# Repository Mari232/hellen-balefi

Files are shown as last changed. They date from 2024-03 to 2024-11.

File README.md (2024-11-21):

# FAQ

Q: How do I get latest hellen-one?

A: ``.github/workflows/update-hellen-one-reference.yaml`` is set to pull latest hellen daily!

Q: I get error 'Cannot stat xx-yy__zz.kicad_pcb: No such file' but files are right there?

A: please do not use dashes and underscore symbols in file names.

Q: Automation says that aux_axis_origin is missing?

A: aux_axis_origin is required, please place it in the appropriate corner.

Q: I get "Cannot parse position" with negative value?

A: Please move origin point into left-bottom corner of the board since we cannot parse negative coordinates at the moment. See https://github.com/andreika-git/hellen-one/issues/349

Q: I am placing an order with JLCPCB and component orientation all looks wrong?!

A: See https://github.com/rusefi/uaefi/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

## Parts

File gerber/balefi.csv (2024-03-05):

Comment | Designator | Footprint | LCSC Part #
MountingHole_Pad | H1 | MountingHole:MountingHole_3.7mm_Pad_Via
MountingHole_Pad | H2 | MountingHole:MountingHole_3.7mm_Pad_Via
MountingHole | H3 | MountingHole:MountingHole_3.7mm
Connectors_EFI_ECUs_Con_825213-1 | J1 | rusefi_lib:825213-1_FIAT
Module-knock-0.2 | M1 | hellen-one-knock-0.2:knock
Module:mega-mcu100/0.3 | M2 | hellen-one-mega-mcu100-0.3:mega-mcu100
Module-vr-discrete-0.4 | M3 | hellen-one-vr-discrete-0.4:vr-discrete
Module-vr-discrete-0.4 | M4 | hellen-one-vr-discrete-0.4:vr-discrete
Q_NIGBT_GCE | Q1 | Package_TO_SOT_SMD:TO-252-2
Q_NIGBT_GCE | Q2 | Package_TO_SOT_SMD:TO-252-2
Q_NMOS_GDS | Q3 | Package_TO_SOT_SMD:TO-252-2
Q_NMOS_GDS | Q4 | Package_TO_SOT_SMD:TO-252-2
Q_NMOS_GDS | Q5 | Package_TO_SOT_SMD:TO-252-2
Q_NMOS_GDS | Q6 | Package_TO_SOT_SMD:TO-252-2
1k | R1 | Resistor_SMD:R_0603_1608Metric
1k | R2 | Resistor_SMD:R_0603_1608Metric
330 | R3 | Resistor_SMD:R_0603_1608Metric
68k | R4 | Resistor_SMD:R_0603_1608Metric
330 | R5 | Resistor_SMD:R_0603_1608Metric
68k | R6 | Resistor_SMD:R_0603_1608Metric
330 | R7 | Resistor_SMD:R_0603_1608Metric
68k | R8 | Resistor_SMD:R_0603_1608Metric
330 | R9 | Resistor_SMD:R_0603_1608Metric
68k | R10 | Resistor_SMD:R_0603_1608Metric

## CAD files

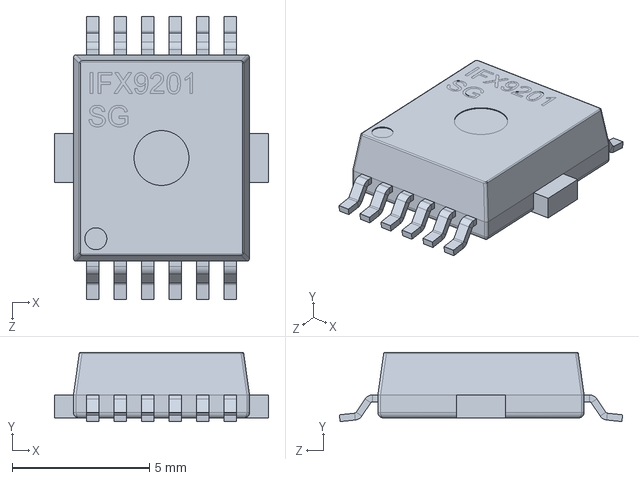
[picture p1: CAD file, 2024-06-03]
balefi-libraries/3d_models/IFX9201SG.STEP
7.80 x 2.52 x 10.3 mm

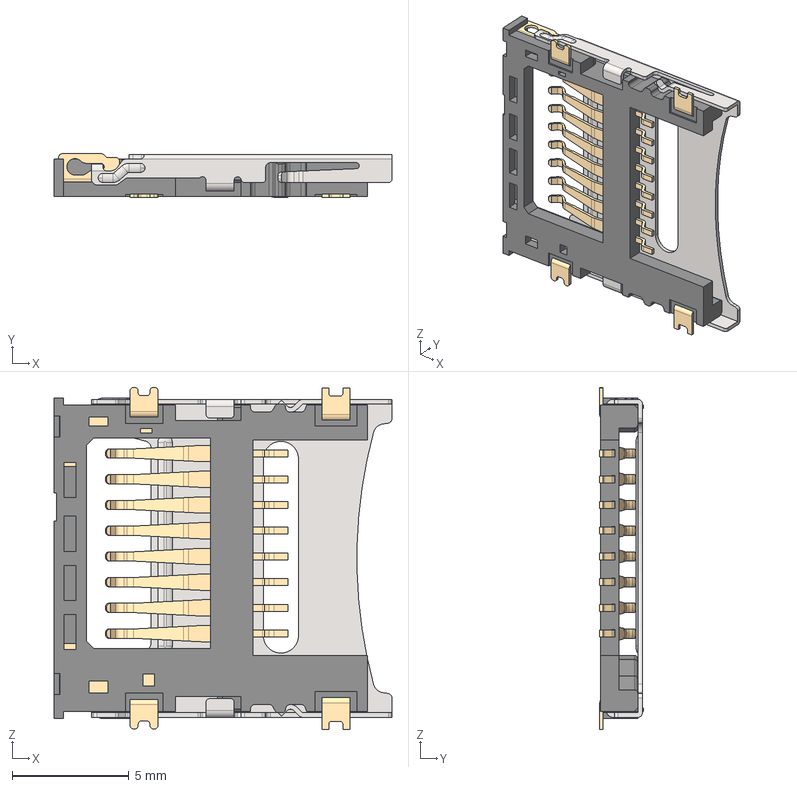
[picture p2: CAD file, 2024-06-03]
balefi-libraries/3d_models/MEM2067-02-180-00-A.stp
14.4 x 1.87 x 14.6 mm
MEM2067-02-180-00-A_PART1
MEM2067-02-180-00-A_PART2
MEM2067-02-180-00-A_PART3
MEM2067-02-180-00-A_PART4
MEM2067-02-180-00-A_PART5
MEM2067-02-180-00-A_PART6
MEM2067-02-180-00-A_PART7
MEM2067-02-180-00-A_PART8
MEM2067-02-180-00-A_PART9
MEM2067-02-180-00-A_PART10
MEM2067-02-180-00-A_PART11
MEM2067-02-180-00-A_PART12
MEM2067-02-180-00-A_PART13
MEM2067-02-180-00-A_PART14

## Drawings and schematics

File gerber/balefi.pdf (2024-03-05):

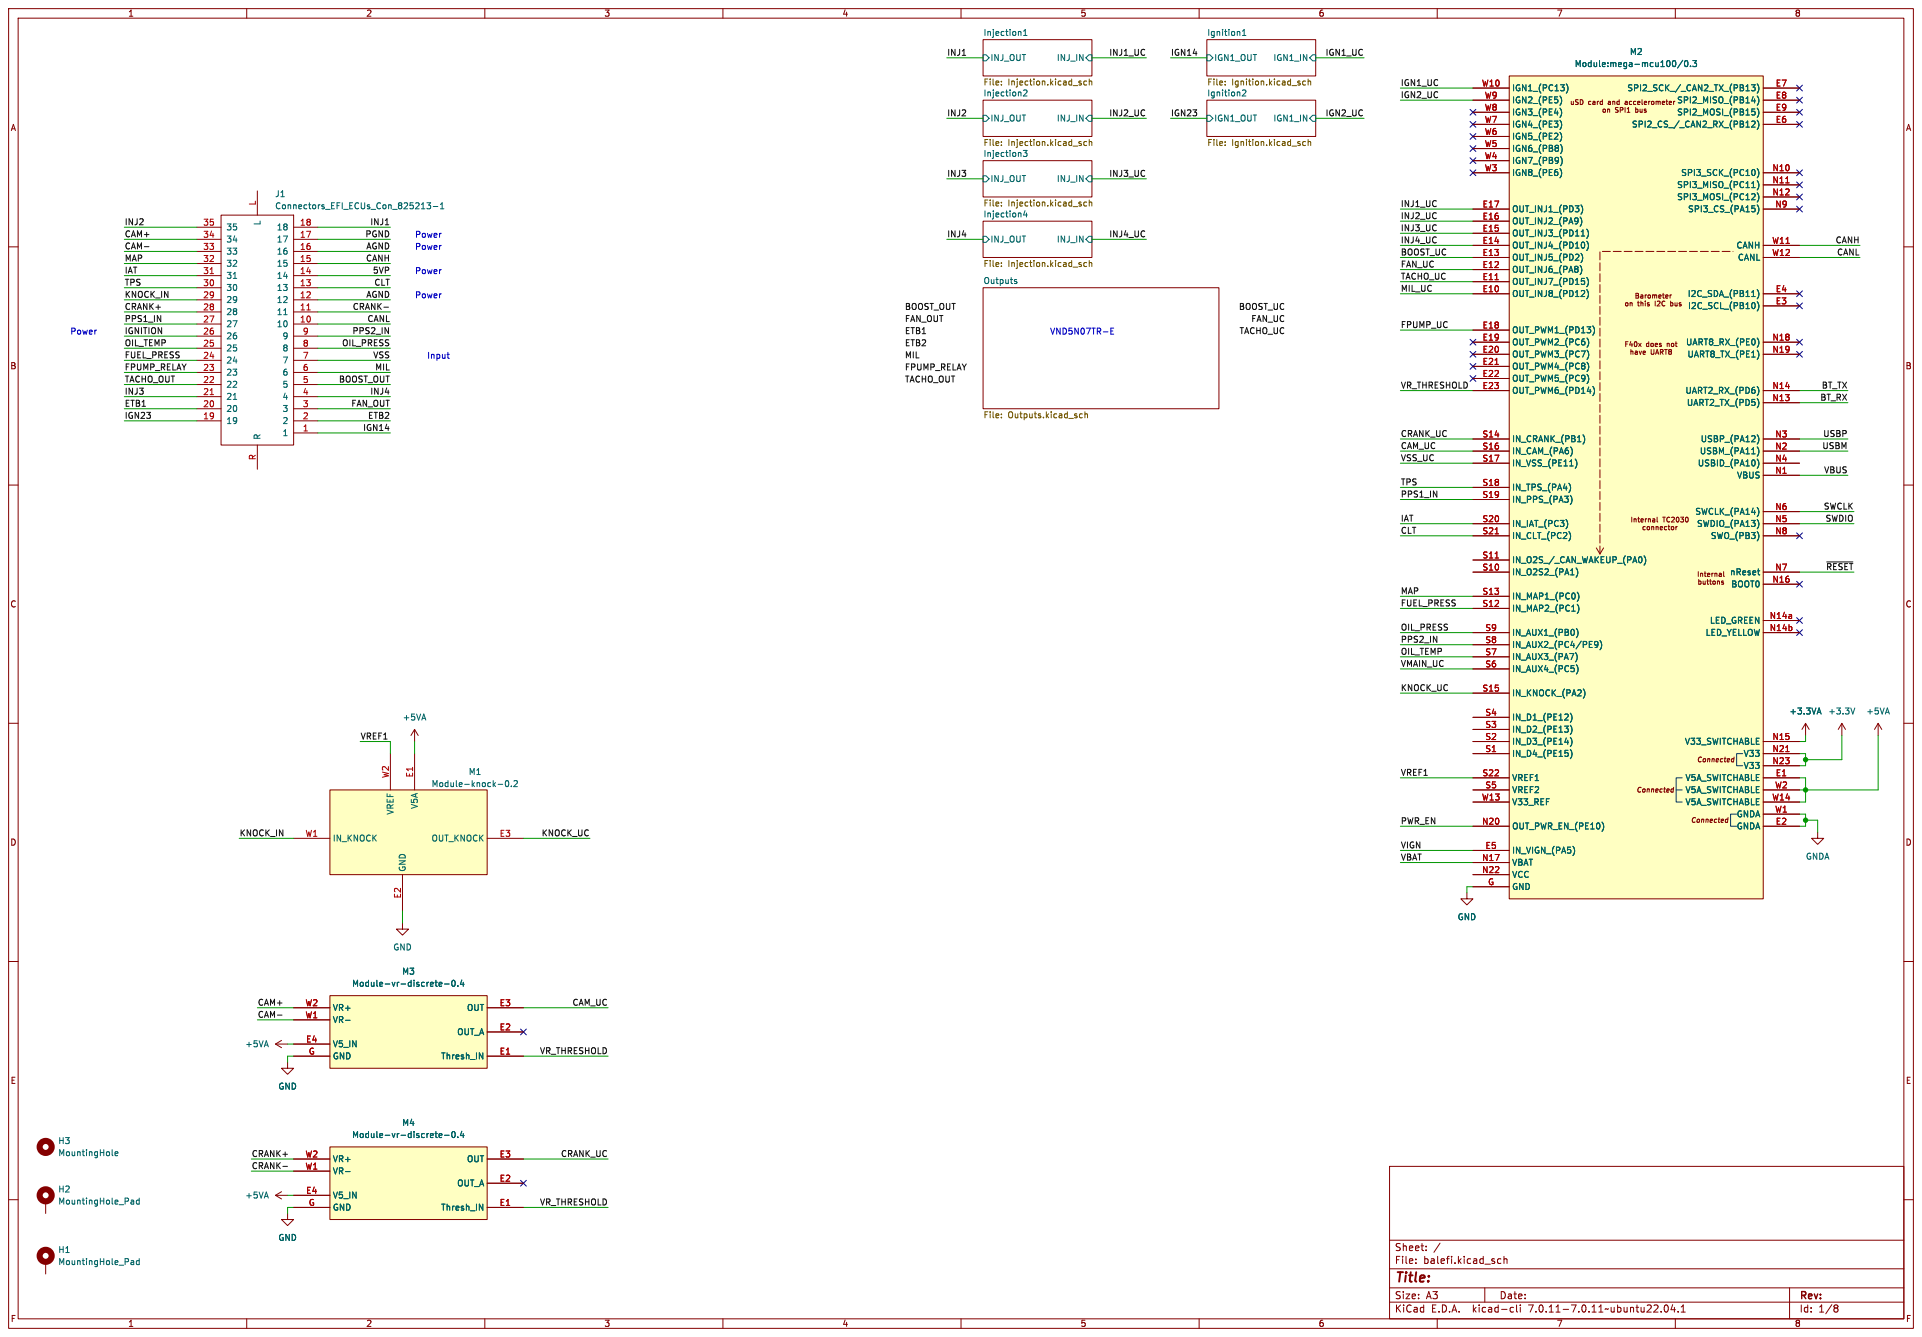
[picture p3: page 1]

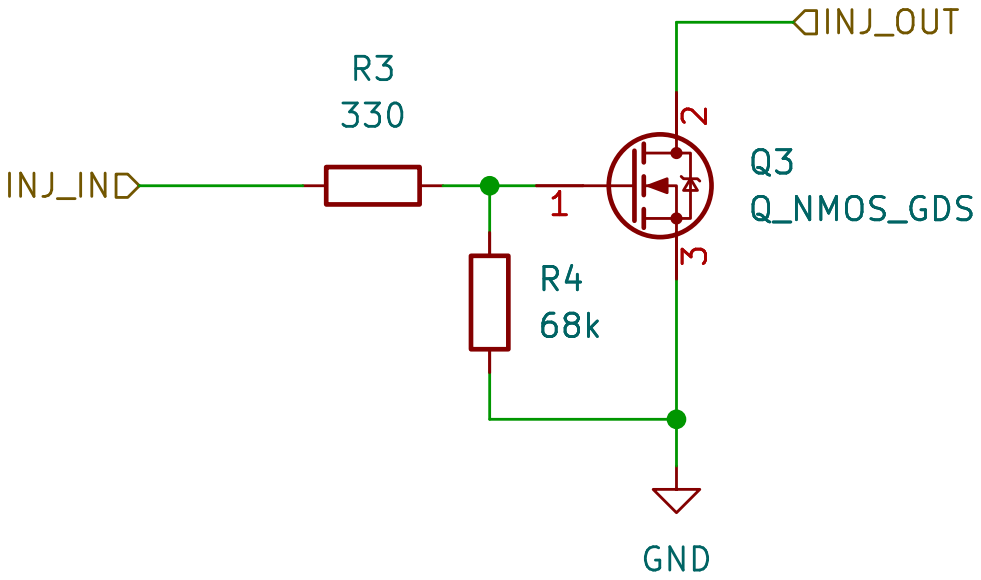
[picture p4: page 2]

Id: 2/8 Title: File: Injection.kicad_sch Sheet: /Injection1/

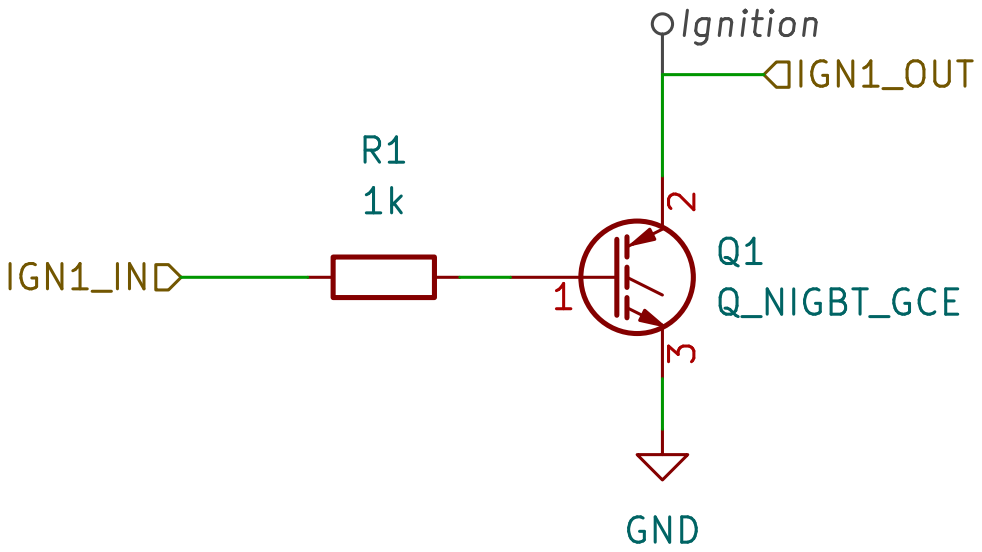
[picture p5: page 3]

Id: 3/8 Title: File: Ignition.kicad_sch Sheet: /Ignition1/

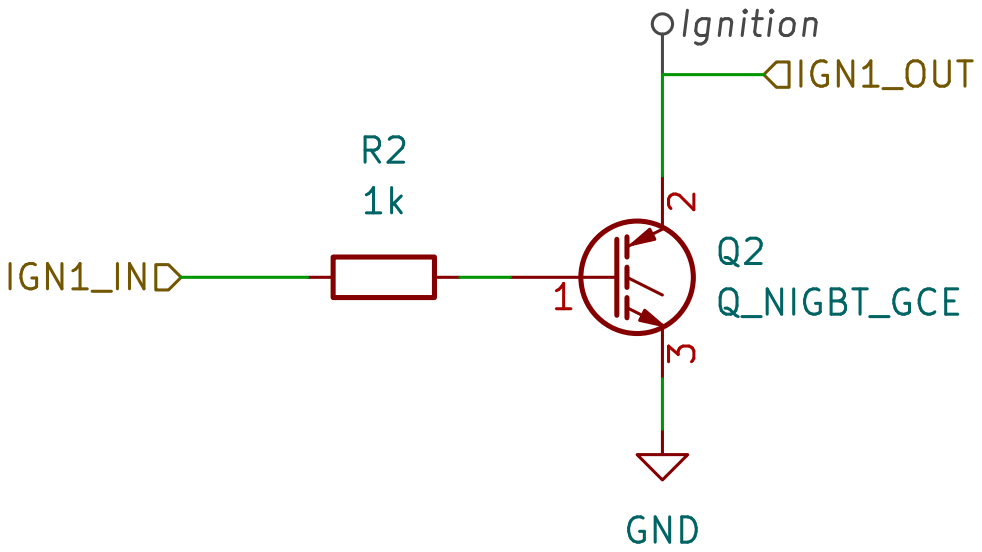
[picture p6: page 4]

Id: 4/8 Title: File: Ignition.kicad_sch Sheet: /Ignition2/

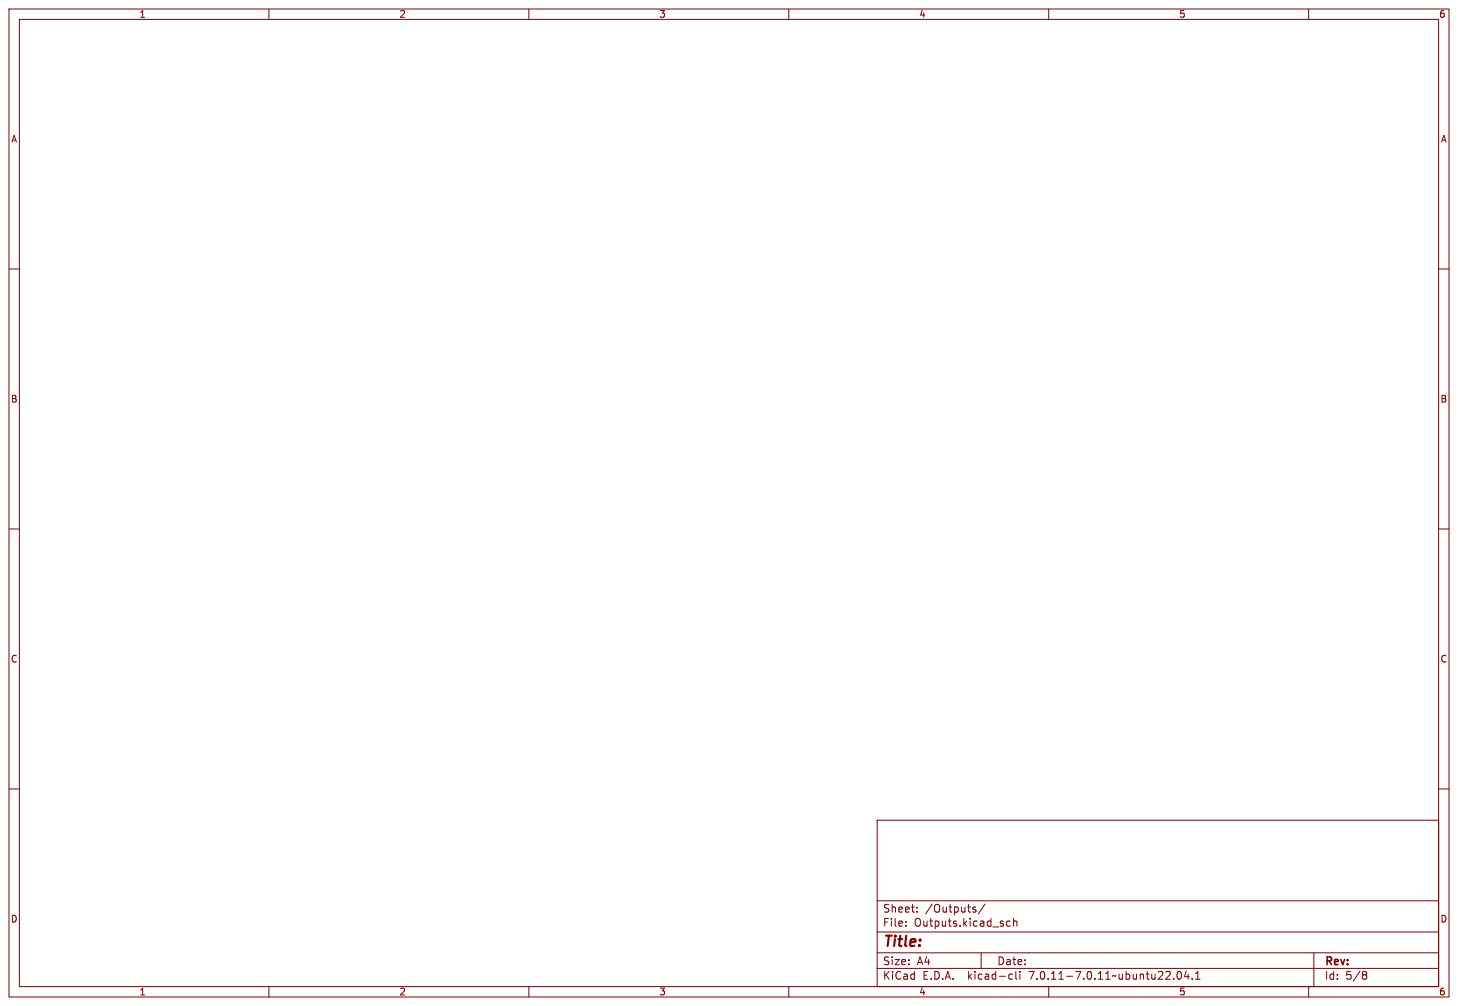
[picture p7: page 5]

Id: 5/8 Title: File: Outputs.kicad_sch Sheet: /Outputs/

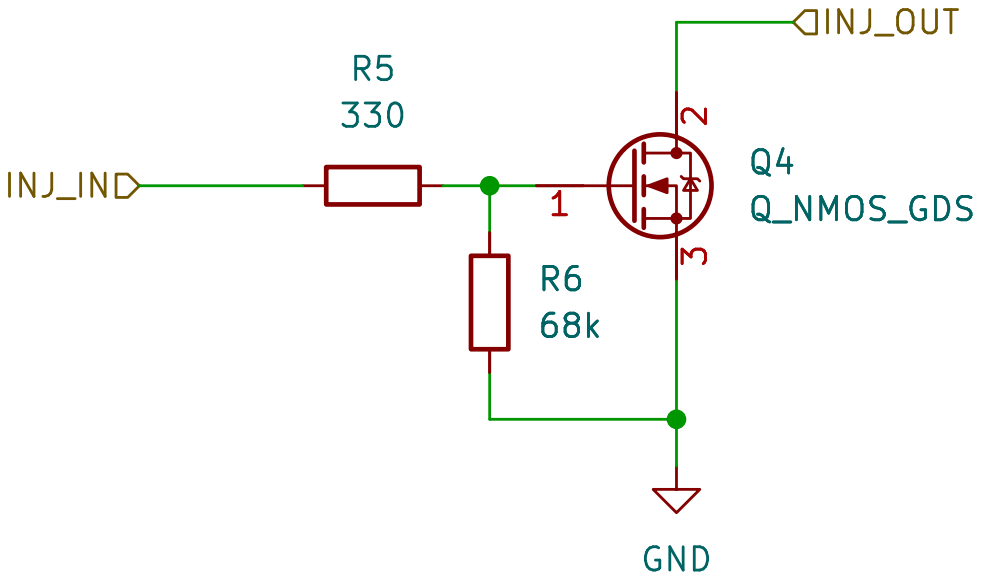
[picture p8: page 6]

Id: 6/8 Title: File: Injection.kicad_sch Sheet: /Injection2/

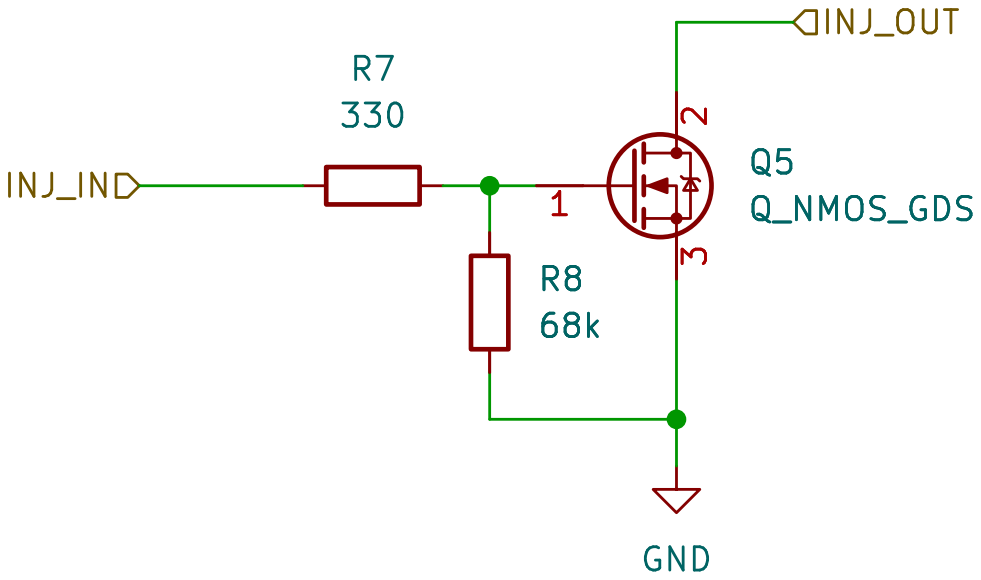
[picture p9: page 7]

Id: 7/8 Title: File: Injection.kicad_sch Sheet: /Injection3/

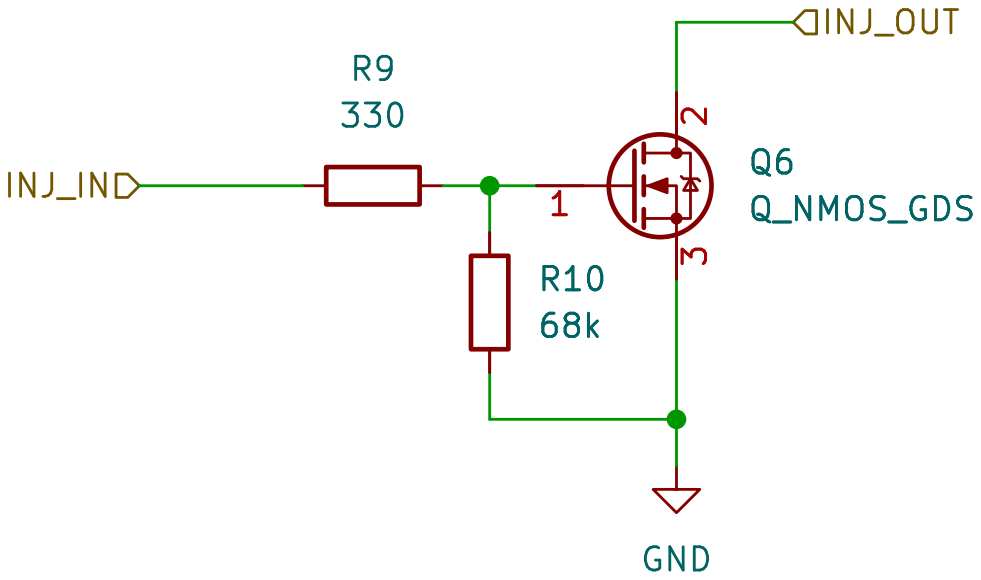
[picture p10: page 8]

Id: 8/8 Title: File: Injection.kicad_sch Sheet: /Injection4/

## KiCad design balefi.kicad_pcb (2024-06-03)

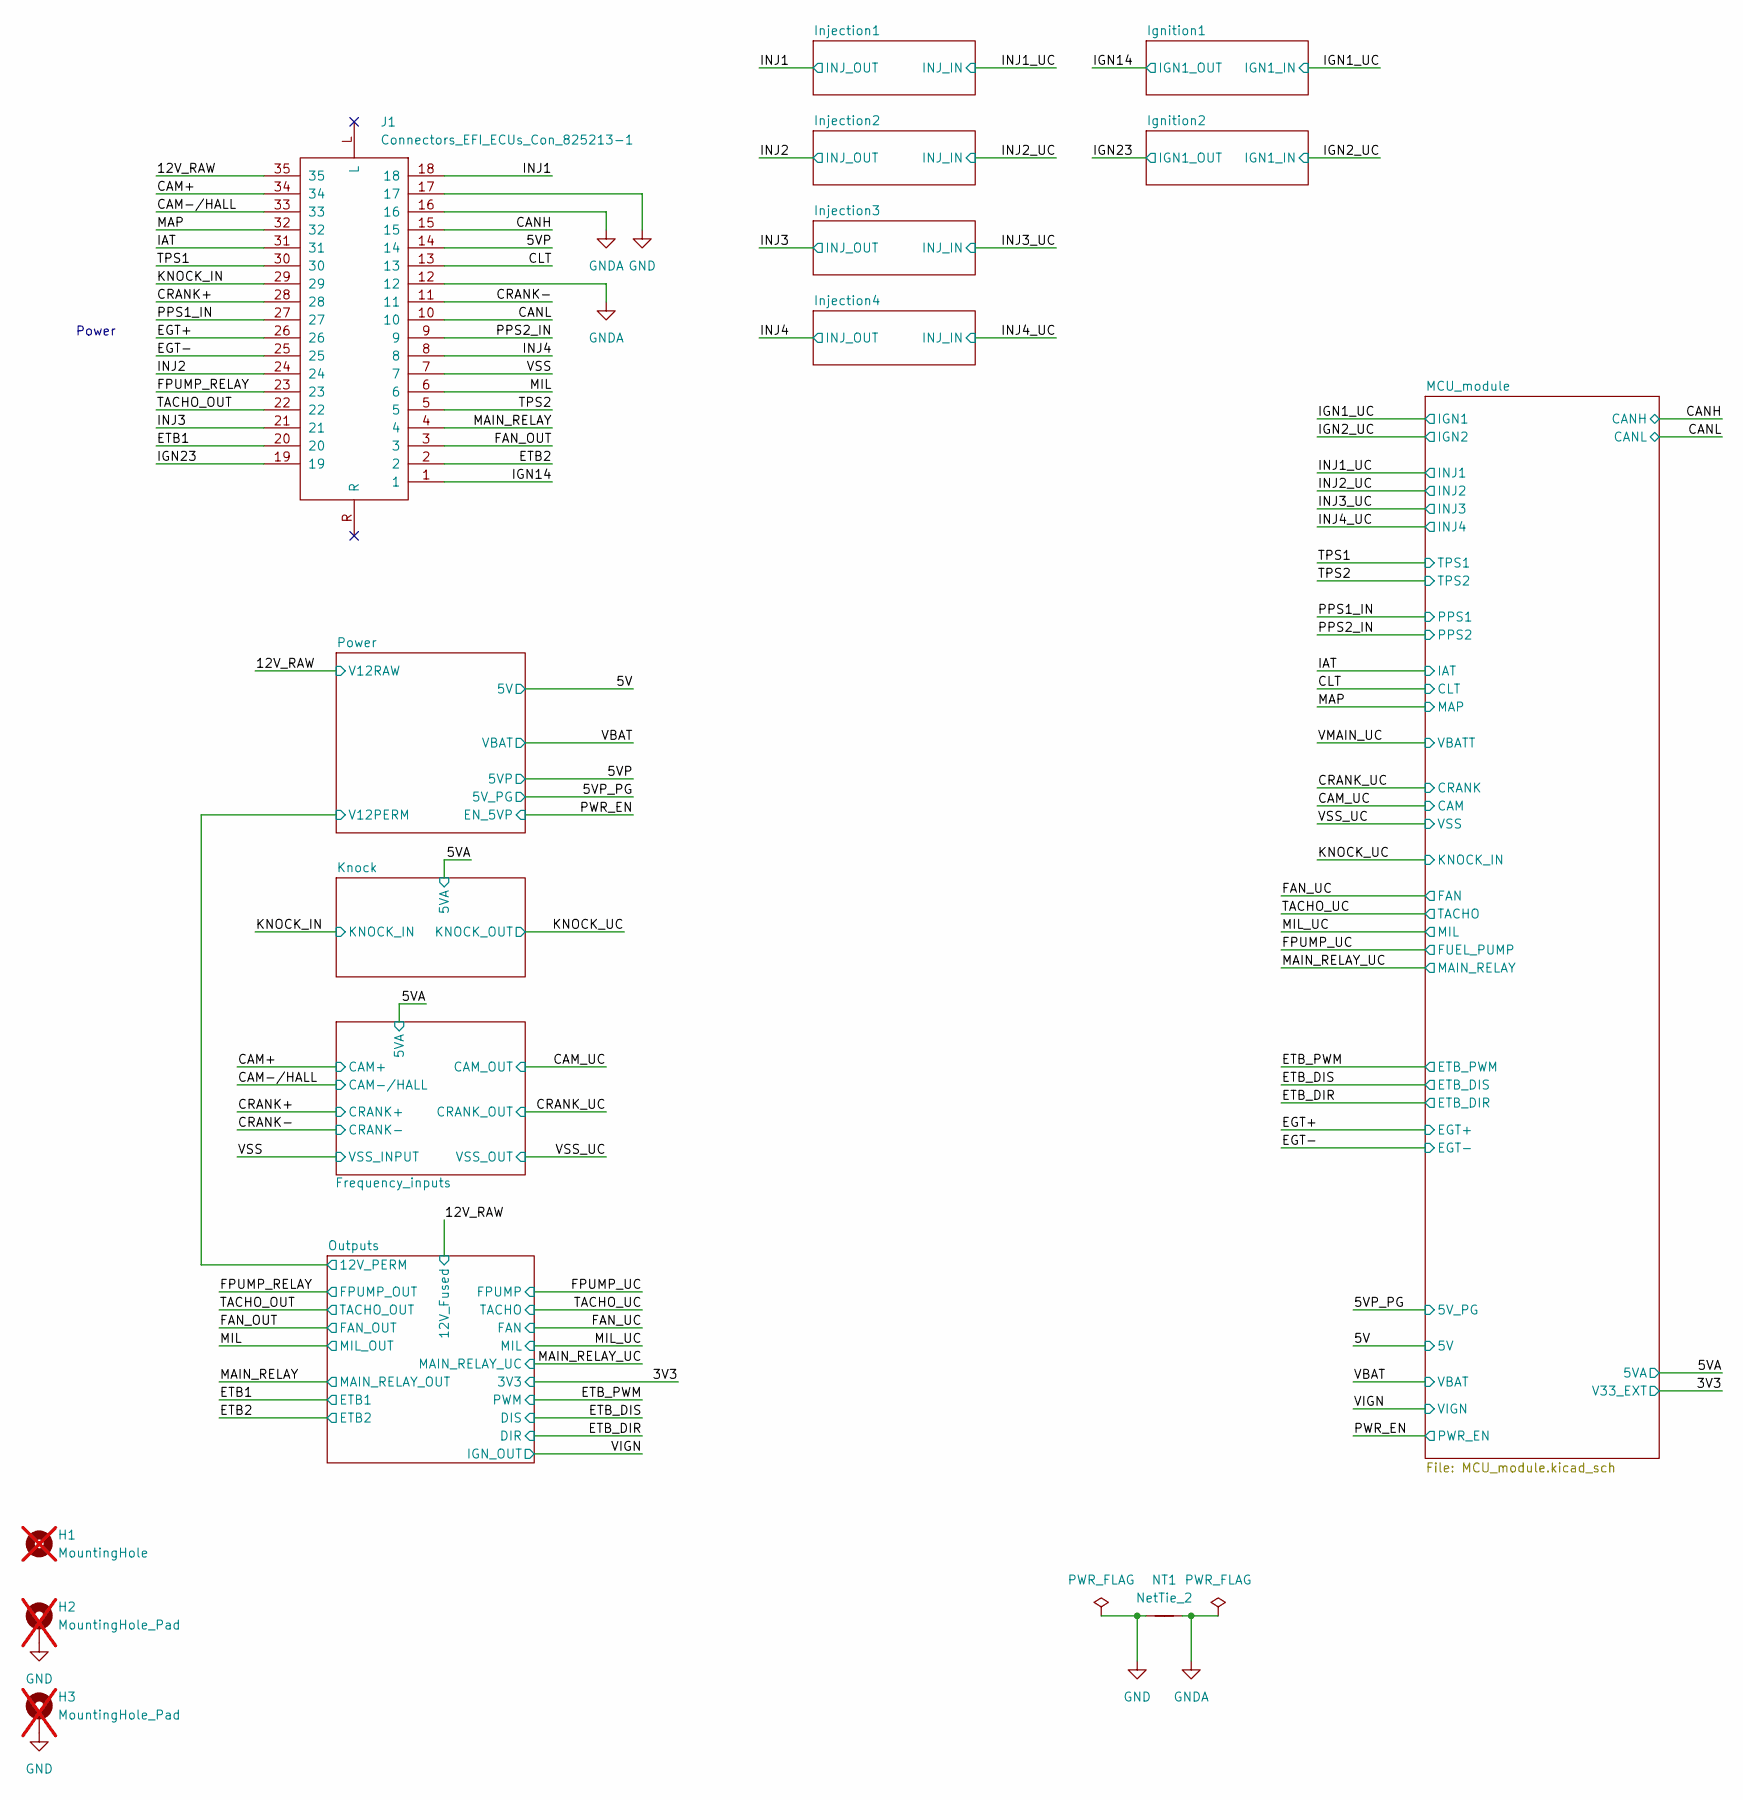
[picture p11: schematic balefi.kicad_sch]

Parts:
H1: MountingHole; MountingHole_3.7mm; not fitted
H2, H3: MountingHole_Pad; MountingHole_3.7mm_Pad_Via; not fitted
J1: Connectors_EFI_ECUs_Con_825213-1; 825213-1_FIAT
NT1: NetTie_2; NetTie-2_SMD_Pad2.0mm

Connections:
/5VP: J1.14; also elsewhere on the board
/12V_RAW: J1.35; also elsewhere on the board
/CAM+: J1.34; also elsewhere on the board
/CAM-/HALL: J1.33; also elsewhere on the board
/CANH: J1.15; also elsewhere on the board
/CANL: J1.10; also elsewhere on the board
/CLT: J1.13; also elsewhere on the board
/CRANK+: J1.28; also elsewhere on the board
/CRANK-: J1.11; also elsewhere on the board
/EGT+: J1.26; also elsewhere on the board
/EGT-: J1.25; also elsewhere on the board
/ETB1: J1.20; also elsewhere on the board
/ETB2: J1.2; also elsewhere on the board
/FAN_OUT: J1.3; also elsewhere on the board
/FPUMP_RELAY: J1.23; also elsewhere on the board
/IAT: J1.31; also elsewhere on the board
/IGN14: J1.1; also elsewhere on the board
/IGN23: J1.19; also elsewhere on the board
/INJ1: J1.18; also elsewhere on the board
/INJ2: J1.24; also elsewhere on the board
/INJ3: J1.21; also elsewhere on the board
/INJ4: J1.8; also elsewhere on the board
/KNOCK_IN: J1.29; also elsewhere on the board
/MAIN_RELAY: J1.4; also elsewhere on the board
/MAP: J1.32; also elsewhere on the board
/MIL: J1.6; also elsewhere on the board
/PPS1_IN: J1.27; also elsewhere on the board
/PPS2_IN: J1.9; also elsewhere on the board
/TACHO_OUT: J1.22; also elsewhere on the board
/TPS1: J1.30; also elsewhere on the board
/TPS2: J1.5; also elsewhere on the board
/VSS: J1.7; also elsewhere on the board
GND: H2.1, H3.1, J1.17, NT1.1; also elsewhere on the board
GNDA: J1.12, J1.16, NT1.2; also elsewhere on the board

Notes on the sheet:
Power

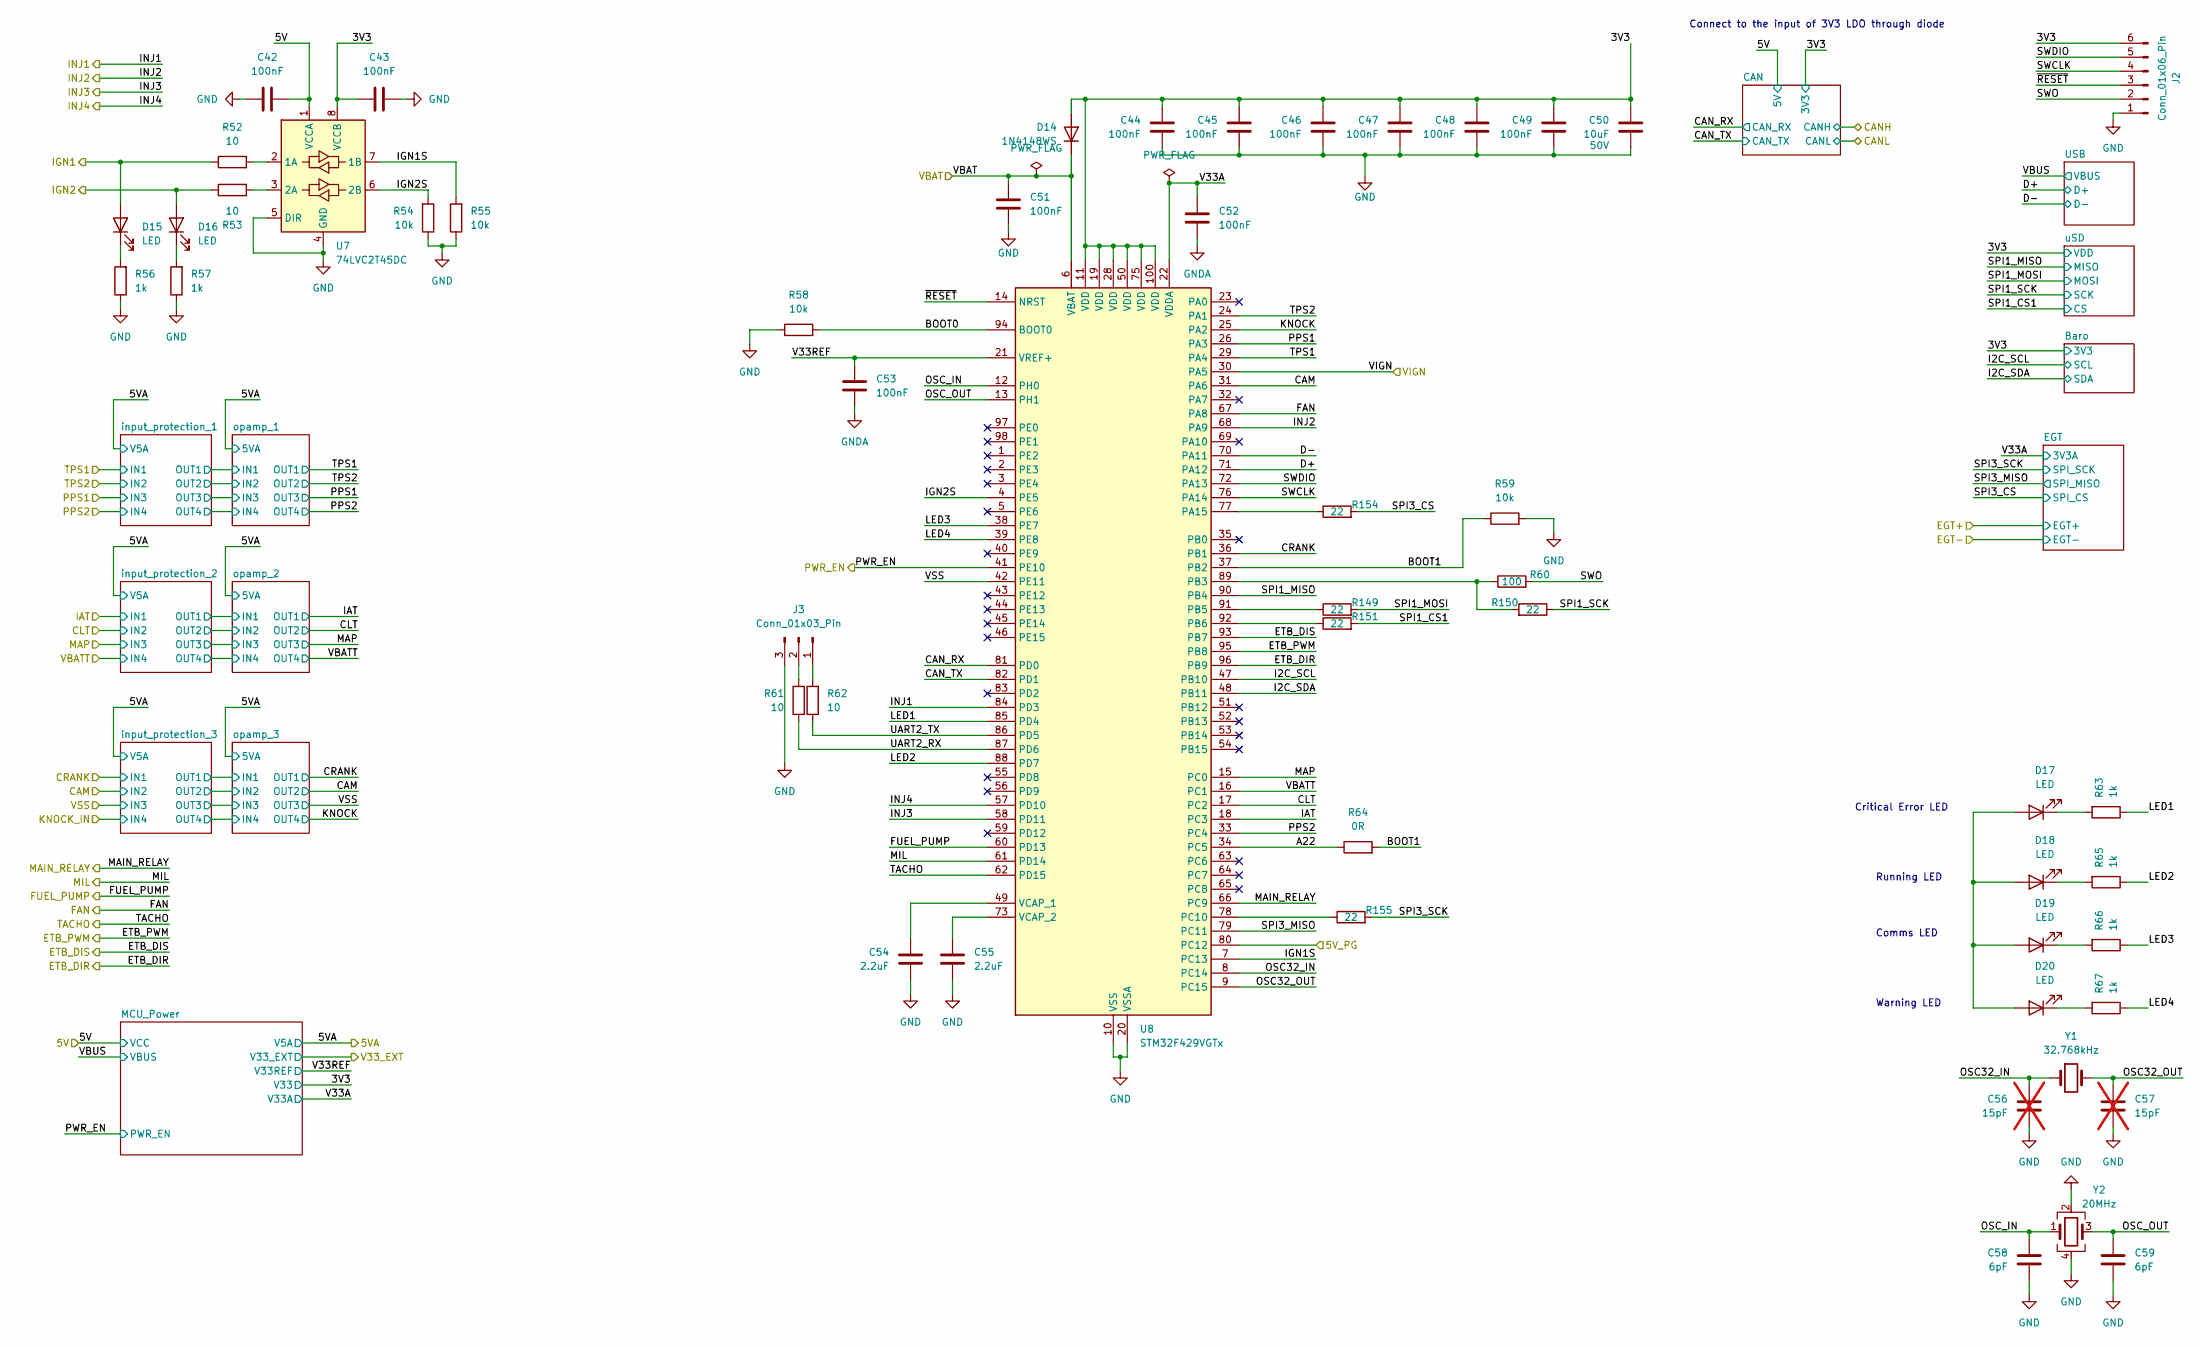
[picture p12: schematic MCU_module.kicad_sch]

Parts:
C42, C43, C44, C45, C46, C47, C48, C49, C51, C52, C53: 100nF; C_0402_1005Metric; MPN CL05B104KB54PNC
C50: 10uF; C_1206_3216Metric; MPN CL31A106KBHNNNE
C54, C55: 2.2uF; C_0805_2012Metric; MPN CL21B225KOFNNNE
C56, C57: 15pF; C_0402_1005Metric; MPN CGA2B2C0G1H150J050BD; not fitted
C58, C59: 6pF; C_0402_1005Metric; MPN GCM1555C1H6R0CA16J
D14: 1N4148WS; D_SOD-323; MPN 1N4148WS-7-F
D15, D16, D17, D18, D19, D20: LED; LED_0603_1608Metric; MPN 150060AS75000
J2: Conn_01x06_Pin; PinHeader_1x06_P2.54mm_Vertical
J3: Conn_01x03_Pin; PinHeader_1x03_P2.54mm_Vertical
R52, R53, R61, R62: 10; R_0402_1005Metric; MPN AC0402FR-0710RL
R54, R55, R58, R59: 10k; R_0402_1005Metric; MPN AC0402JR-0710KL
R56, R57, R63, R65, R66, R67: 1k; R_0402_1005Metric; MPN AC0402FR-071KL
R60: 100; R_0402_1005Metric; MPN AC0402FR-07100RL
R64: 0R; R_0402_1005Metric; MPN AC0402JR-070RL
R149, R150, R151, R154, R155: 22; R_0402_1005Metric; MPN AC0402FR-0722RL
U7: 74LVC2T45DC; VSSOP-8_2.3x2mm_P0.5mm; MPN 74LVC2T45DC-Q100H
U8: STM32F429VGTx; LQFP-100_14x14mm_P0.5mm; MPN STM32F429VGT6
Y1: 32.768kHz; Crystal_SMD_2012-2Pin_2.0x1.2mm; MPN ECS-.327-CDX-1082
Y2: 20MHz; Crystal_SMD_2520-4Pin_2.5x2.0mm; MPN ECS-200-8-36Q-AES-TR

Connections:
/5V: C42.2, U7.1 (VCCA); also elsewhere on the board
/5VP_PG: U8.80 (PC12); also elsewhere on the board
/CAM_UC: U8.31 (PA6); also elsewhere on the board
/CLT: U8.17 (PC2); also elsewhere on the board
/CRANK_UC: U8.36 (PB1); also elsewhere on the board
/ETB_DIR: U8.96 (PB9); also elsewhere on the board
/ETB_DIS: U8.93 (PB7); also elsewhere on the board
/ETB_PWM: U8.95 (PB8); also elsewhere on the board
/FAN_UC: U8.67 (PA8); also elsewhere on the board
/FPUMP_UC: U8.60 (PD13); also elsewhere on the board
/IAT: U8.18 (PC3); also elsewhere on the board
/IGN1_UC: D15.2 (A), R52.1; also elsewhere on the board
/IGN2_UC: D16.2 (A), R53.1; also elsewhere on the board
/INJ1_UC: U8.84 (PD3); also elsewhere on the board
/INJ2_UC: U8.68 (PA9); also elsewhere on the board
/INJ3_UC: U8.58 (PD11); also elsewhere on the board
/INJ4_UC: U8.57 (PD10); also elsewhere on the board
/MAIN_RELAY_UC: U8.66 (PC9); also elsewhere on the board
/MAP: U8.15 (PC0); also elsewhere on the board
/MCU_module/3V3: C43.1, C44.1, C45.1, C46.1, C47.1, C48.1, C49.1, C50.1, D14.2 (A), J2.6, U7.8 (VCCB), U8.11 (VDD), U8.19 (VDD), U8.28 (VDD), U8.50 (VDD), U8.75 (VDD), U8.100 (VDD); also elsewhere on the board
/MCU_module/A22: R64.1, U8.34 (PC5)
/MCU_module/BOOT0: R58.2, U8.94 (BOOT0)
/MCU_module/BOOT1: R59.1, R64.2, U8.37 (PB2)
/MCU_module/CAN_RX: U8.81 (PD0); also elsewhere on the board
/MCU_module/CAN_TX: U8.82 (PD1); also elsewhere on the board
/MCU_module/D+: U8.71 (PA12); also elsewhere on the board
/MCU_module/D-: U8.70 (PA11); also elsewhere on the board
/MCU_module/I2C_SCL: U8.47 (PB10); also elsewhere on the board
/MCU_module/I2C_SDA: U8.48 (PB11); also elsewhere on the board
/MCU_module/IGN1S: R55.2, U7.7 (1B), U8.7 (PC13)
/MCU_module/IGN2S: R54.2, U7.6 (2B), U8.4 (PE5)
/MCU_module/KNOCK: U8.25 (PA2); also elsewhere on the board
/MCU_module/LED1: R63.1, U8.85 (PD4)
/MCU_module/LED2: R65.1, U8.88 (PD7)
/MCU_module/LED3: R66.1, U8.38 (PE7)
/MCU_module/LED4: R67.1, U8.39 (PE8)
/MCU_module/OSC32_IN: C56.1, U8.8 (PC14), Y1.1
/MCU_module/OSC32_OUT: C57.1, U8.9 (PC15), Y1.2
/MCU_module/OSC_IN: C58.1, U8.12 (PH0), Y2.1
/MCU_module/OSC_OUT: C59.1, U8.13 (PH1), Y2.3
/MCU_module/SPI1_CS1: R151.2; also elsewhere on the board
/MCU_module/SPI1_MISO: U8.90 (PB4); also elsewhere on the board
/MCU_module/SPI1_MOSI: R149.2; also elsewhere on the board
/MCU_module/SPI1_SCK: R150.1; also elsewhere on the board
/MCU_module/SPI3_CS: R154.2; also elsewhere on the board
/MCU_module/SPI3_MISO: U8.79 (PC11); also elsewhere on the board
/MCU_module/SPI3_SCK: R155.2; also elsewhere on the board
/MCU_module/SWCLK: J2.4, U8.76 (PA14)
/MCU_module/SWDIO: J2.5, U8.72 (PA13)
/MCU_module/SWO: J2.2, R60.2
/MCU_module/UART2_RX: R61.2, U8.87 (PD6)
/MCU_module/UART2_TX: R62.1, U8.86 (PD5)
/MCU_module/V33A: C52.1, U8.22 (VDDA); also elsewhere on the board
/MCU_module/V33REF: C53.1, U8.21 (VREF+); also elsewhere on the board
/MCU_module/~RESET: J2.3, U8.14 (NRST)
/MIL_UC: U8.61 (PD14); also elsewhere on the board
/PPS1_IN: U8.26 (PA3); also elsewhere on the board
/PPS2_IN: U8.33 (PC4); also elsewhere on the board
/PWR_EN: U8.41 (PE10); also elsewhere on the board
/TACHO_UC: U8.62 (PD15); also elsewhere on the board
/TPS1: U8.29 (PA4); also elsewhere on the board
/TPS2: U8.24 (PA1); also elsewhere on the board
/VBAT: C51.1, D14.1 (K), U8.6 (VBAT); also elsewhere on the board
/VIGN: U8.30 (PA5); also elsewhere on the board
/VMAIN_UC: U8.16 (PC1); also elsewhere on the board
/VSS_UC: U8.42 (PE11); also elsewhere on the board
GND: C42.1, C43.2, C44.2, C45.2, C46.2, C47.2, C48.2, C49.2, C50.2, C51.2, C54.2, C55.2, C56.2, C57.2, C58.2, C59.2, J2.1, J3.3, R54.1, R55.1, R56.1, R57.1, R58.1, R59.2, U7.4 (GND), U7.5 (DIR), U8.10 (VSS), U8.20 (VSSA), U8.27 (VSS), U8.74 (VSS), U8.99 (VSS), Y2.2, Y2.4; also elsewhere on the board
GNDA: C52.2, C53.2; also elsewhere on the board
unnamed: D15.1 (K), R56.2
unnamed: D16.1 (K), R57.2
unnamed: D17.2 (A), D18.2 (A), D19.2 (A), D20.2 (A)
unnamed: D17.1 (K), R63.2
unnamed: D18.1 (K), R65.2
unnamed: D19.1 (K), R66.2
unnamed: D20.1 (K), R67.2
unnamed: J3.1, R62.2
unnamed: J3.2, R61.1
unnamed: R52.2, U7.2 (1A)
unnamed: R53.2, U7.3 (2A)
unnamed: R154.1, U8.77 (PA15)
unnamed: R60.1, R150.2, U8.89 (PB3)
unnamed: R149.1, U8.91 (PB5)
unnamed: R151.1, U8.92 (PB6)
unnamed: R155.1, U8.78 (PC10)
unnamed: C54.1, U8.49 (VCAP_1)
unnamed: C55.1, U8.73 (VCAP_2)

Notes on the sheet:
Connect to the input of 3V3 LDO through diode
Critical Error LED
Running LED
Warning LED
Comms LED

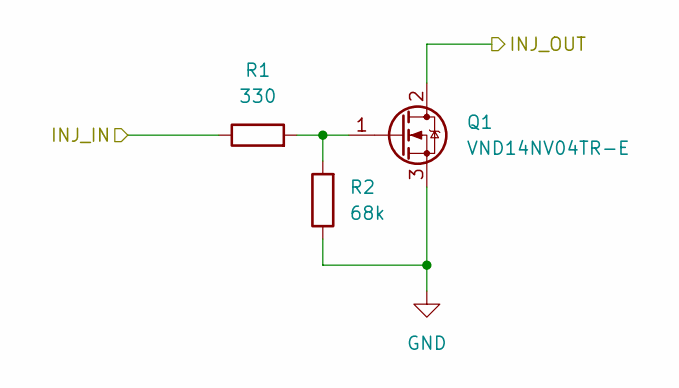
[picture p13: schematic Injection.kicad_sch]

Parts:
Q1: VND14NV04TR-E; TO-252-2; MPN VND14NV04TR-E
R1: 330; R_0402_1005Metric; MPN AC0402FR-07330RL
R2: 68k; R_0402_1005Metric; MPN AC0402FR-0768KL

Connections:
/INJ1: Q1.2 (D); also elsewhere on the board
/INJ1_UC: R1.1; also elsewhere on the board
GND: Q1.3 (S), R2.1; also elsewhere on the board
unnamed: Q1.1 (G), R1.2, R2.2

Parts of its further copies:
Q2, Q3, Q4: VND14NV04TR-E; TO-252-2; MPN VND14NV04TR-E
R3, R5, R7: 330; R_0402_1005Metric; MPN AC0402FR-07330RL
R4, R6, R8: 68k; R_0402_1005Metric; MPN AC0402FR-0768KL

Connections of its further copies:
/INJ2: Q2.2 (D); also elsewhere on the board
/INJ2_UC: R3.1; also elsewhere on the board
/INJ3: Q3.2 (D); also elsewhere on the board
/INJ3_UC: R5.1; also elsewhere on the board
/INJ4: Q4.2 (D); also elsewhere on the board
/INJ4_UC: R7.1; also elsewhere on the board
GND: Q2.3 (S), Q3.3 (S), Q4.3 (S), R4.1, R6.1, R8.1; also elsewhere on the board
unnamed: Q2.1 (G), R3.2, R4.2
unnamed: Q3.1 (G), R5.2, R6.2
unnamed: Q4.1 (G), R7.2, R8.2

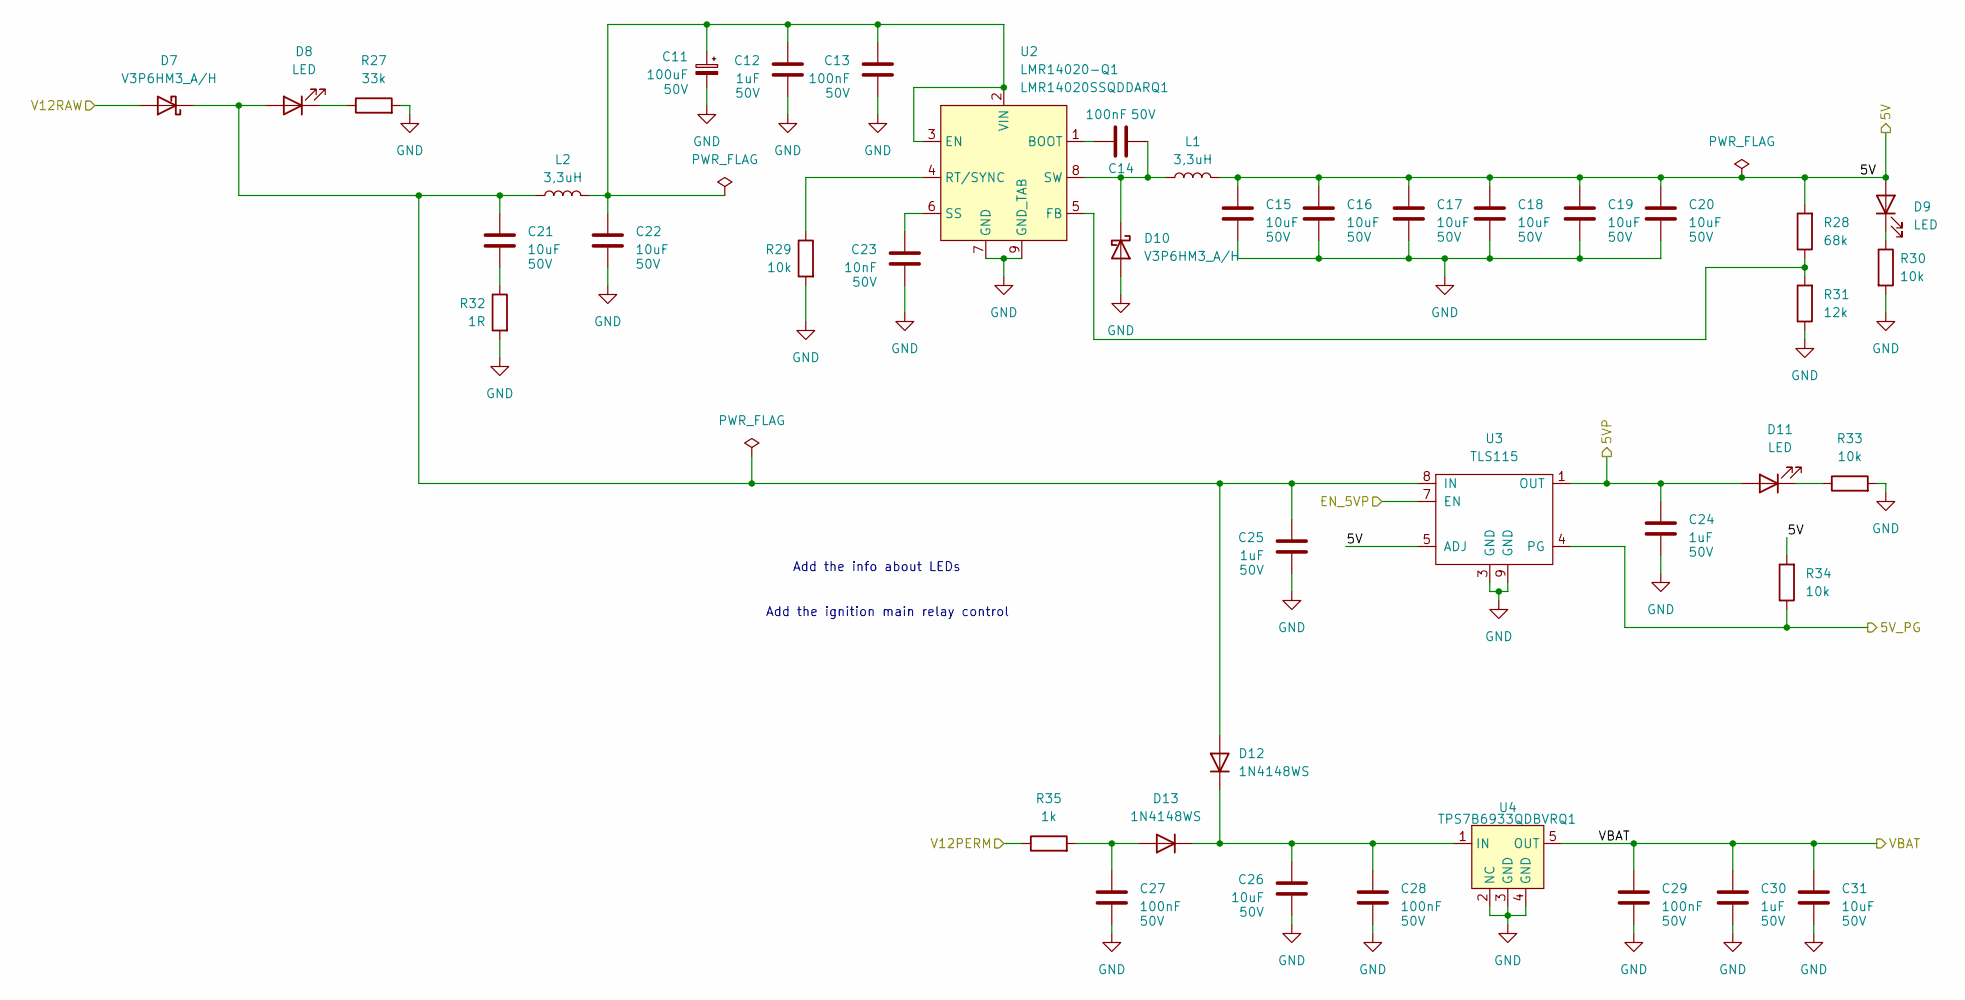
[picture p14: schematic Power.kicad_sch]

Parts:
C11: 100uF; CP_Elec_8x10; MPN UCD1H101MNL1GS
C12, C24, C25, C30: 1uF; C_0805_2012Metric; MPN CL21B105KBFNNNG
C13, C14, C27, C28, C29: 100nF; C_0402_1005Metric; MPN CL05B104KB54PNC
C15, C16, C17, C18, C19, C20, C21, C22, C26, C31: 10uF; C_1206_3216Metric; MPN CL31A106KBHNNNE
C23: 10nF; C_0402_1005Metric; MPN GCM155R71H103MA55D
D7, D10: V3P6HM3_A/H; Vishay_SMPA; MPN V3P6HM3_A/H
D8, D9, D11: LED; LED_0603_1608Metric; MPN 150060AS75000
D12, D13: 1N4148WS; D_SOD-323; MPN 1N4148WS-7-F
L1, L2: 3,3uH; L_TDK_VLS6045EX_VLS6045AF; MPN VLS6045EX-3R3N-H
R27: 33k; R_0402_1005Metric; MPN AC0402FR-0733KL
R28: 68k; R_0402_1005Metric; MPN AC0402FR-0768KL
R29, R30, R33, R34: 10k; R_0402_1005Metric; MPN AC0402JR-0710KL
R31: 12k; R_0402_1005Metric; MPN AC0402FR-0712KL
R32: 1R; R_0603_1608Metric; MPN AF0603FR-071RL
R35: 1k; R_0402_1005Metric; MPN AC0402FR-071KL
U2: LMR14020-Q1; Texas_R-PDSO-G8_EP2.95x4.9mm_Mask2.4x3.1mm_ThermalVias; MPN LMR14020SSQDDARQ1
U3: TLS115; Texas_R-PDSO-G8_EP2.95x4.9mm_Mask2.4x3.1mm_ThermalVias; MPN TLS115B0EJXUMA1
U4: TPS7B6933QDBVRQ1; SOT-23-5; MPN TPS7B6933QDBVRQ1

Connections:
/5V: C15.1, C16.1, C17.1, C18.1, C19.1, C20.1, D9.2 (A), L1.2, R28.2, R34.2, U3.5 (ADJ); also elsewhere on the board
/5VP: C24.1, D11.2 (A), U3.1 (OUT); also elsewhere on the board
/5VP_PG: R34.1, U3.4 (PG); also elsewhere on the board
/12V_RAW: D7.2 (A); also elsewhere on the board
/Outputs/12V_PERM: R35.1; also elsewhere on the board
/PWR_EN: U3.7 (EN); also elsewhere on the board
/VBAT: C29.1, C30.1, C31.1, U4.5 (OUT); also elsewhere on the board
GND: C11.2, C12.2, C13.2, C15.2, C16.2, C17.2, C18.2, C19.2, C20.2, C22.2, C23.2, C24.2, C25.2, C26.2, C27.2, C28.2, C29.2, C30.2, C31.2, D10.2 (A), R27.2, R29.2, R30.2, R31.1, R32.2, R33.2, U2.7 (GND), U2.9 (GND_TAB), U3.3 (GND), U3.9 (GND), U4.2 (NC), U4.3 (GND), U4.4 (GND); also elsewhere on the board
unnamed: C21.2, R32.1
unnamed: D8.1 (K), R27.1
unnamed: D9.1 (K), R30.1
unnamed: C14.1, D10.1 (K), L1.1, U2.8 (SW)
unnamed: D11.1 (K), R33.1
unnamed: C21.1, C25.1, D7.1 (K), D8.2 (A), D12.2 (A), L2.1, U3.8 (IN)
unnamed: C26.1, C28.1, D12.1 (K), D13.1 (K), U4.1 (IN)
unnamed: C27.1, D13.2 (A), R35.2
unnamed: C14.2, U2.1 (BOOT)
unnamed: C11.1, C12.1, C13.1, C22.1, L2.2, U2.2 (VIN), U2.3 (EN)
unnamed: R28.1, R31.2, U2.5 (FB)
unnamed: R29.1, U2.4 (RT/SYNC)
unnamed: C23.1, U2.6 (SS)

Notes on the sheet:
Add the info about LEDs
Add the ignition main relay control

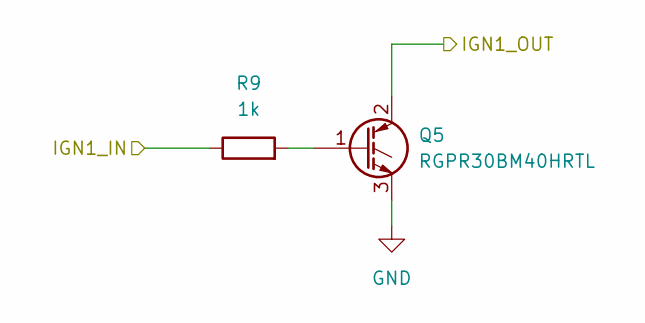
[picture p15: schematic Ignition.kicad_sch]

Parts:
Q5: RGPR30BM40HRTL; TO-252-2; MPN RGPR30BM40HRTL
R9: 1k; R_0402_1005Metric; MPN AC0402FR-071KL

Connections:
/IGN1_UC: R9.1; also elsewhere on the board
/IGN14: Q5.2 (C); also elsewhere on the board
GND: Q5.3 (E); also elsewhere on the board
unnamed: Q5.1 (G), R9.2

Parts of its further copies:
Q6: RGPR30BM40HRTL; TO-252-2; MPN RGPR30BM40HRTL
R10: 1k; R_0402_1005Metric; MPN AC0402FR-071KL

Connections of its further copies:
/IGN2_UC: R10.1; also elsewhere on the board
/IGN23: Q6.2 (C); also elsewhere on the board
GND: Q6.3 (E); also elsewhere on the board
unnamed: Q6.1 (G), R10.2

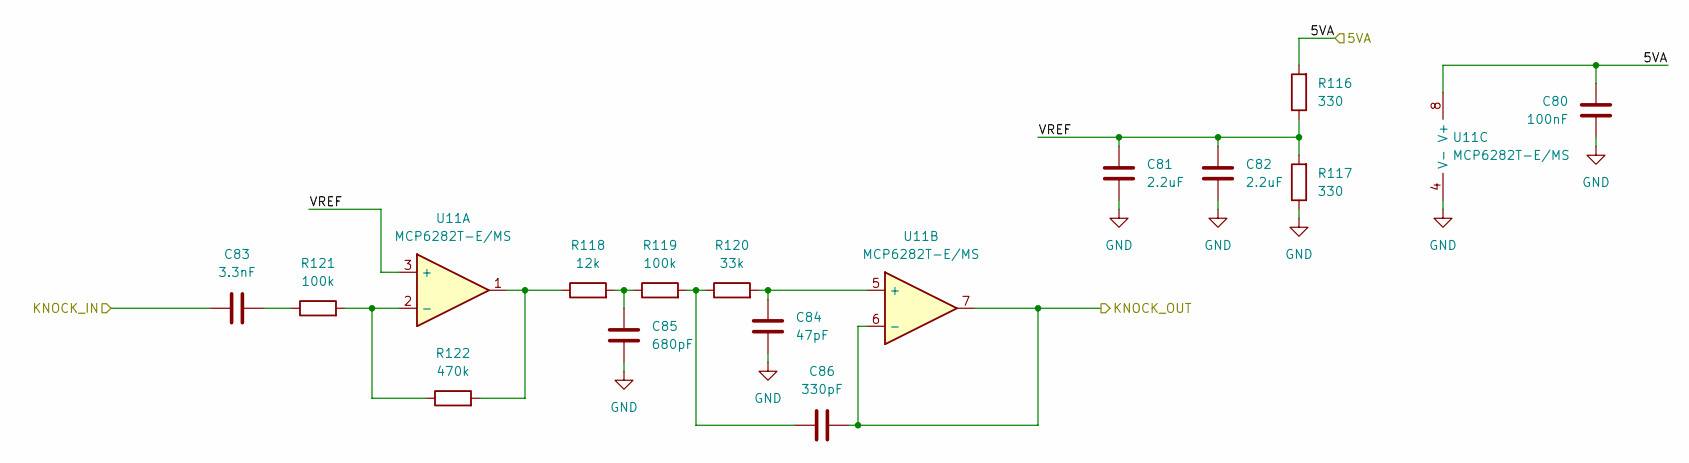
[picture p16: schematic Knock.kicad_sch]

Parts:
C80: 100nF; C_0402_1005Metric; MPN CL05B104KB54PNC
C81, C82: 2.2uF; C_0805_2012Metric; MPN CL21B225KOFNNNE
C83: 3.3nF; C_0402_1005Metric; MPN GCM155R71H332KA37D
C84: 47pF; C_0402_1005Metric; MPN CL05C470JB51PNC
C85: 680pF; C_0402_1005Metric; MPN GCM155R71H681KA37J
C86: 330pF; C_0402_1005Metric; MPN GCM155R71H331KA37D
R116, R117: 330; R_0402_1005Metric; MPN AC0402FR-07330RL
R118: 12k; R_0402_1005Metric; MPN AC0402FR-0712KL
R119, R121: 100k; R_0402_1005Metric; MPN AC0402FR-07100KL
R120: 33k; R_0402_1005Metric; MPN AC0402FR-0733KL
R122: 470k; R_0402_1005Metric
U11: MCP6282T-E/MS; MSOP-8_3x3mm_P0.65mm; MPN MCP6282T-E/MS

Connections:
/5VA: C80.1, R116.2, U11.8 (V+); also elsewhere on the board
/KNOCK_IN: C83.1; also elsewhere on the board
/KNOCK_UC: C86.1, U11.6 (-), U11.7; also elsewhere on the board
/Knock/VREF: C81.1, C82.1, R116.1, R117.2, U11.3 (+)
GND: C80.2, C81.2, C82.2, C84.1, C85.1, R117.1, U11.4 (V-); also elsewhere on the board
unnamed: C83.2, R121.1
unnamed: C85.2, R118.2, R119.1
unnamed: C86.2, R119.2, R120.1
unnamed: R118.1, R122.2, U11.1
unnamed: R121.2, R122.1, U11.2 (-)
unnamed: C84.2, R120.2, U11.5 (+)

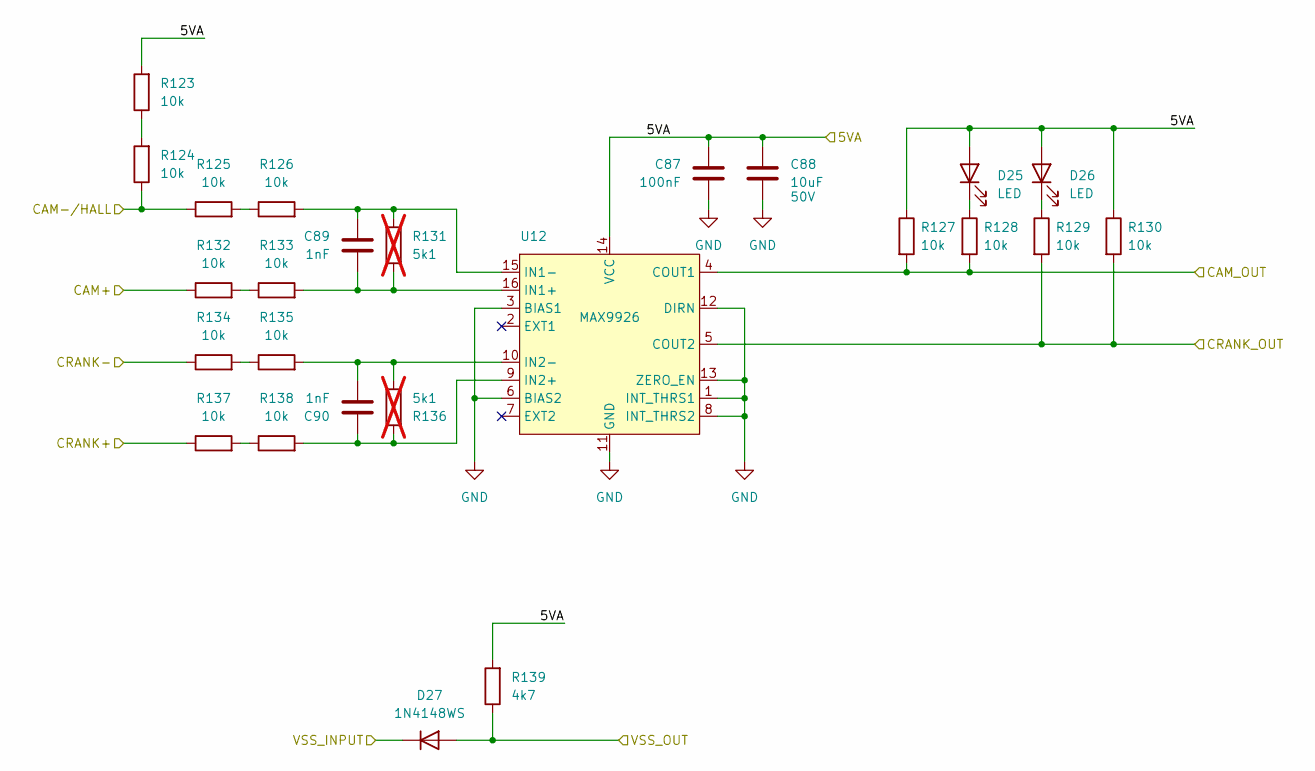
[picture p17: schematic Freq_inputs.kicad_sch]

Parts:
C87: 100nF; C_0402_1005Metric; MPN CL05B104KB54PNC
C88: 10uF; C_1206_3216Metric; MPN CL31A106KBHNNNE
C89, C90: 1nF; C_0805_2012Metric; MPN CL10B102KB8WPNC
D25, D26: LED; LED_0603_1608Metric; MPN 150060AS75000
D27: 1N4148WS; D_SOD-323; MPN 1N4148WS-7-F
R123, R124, R125, R126, R132, R133, R134, R135, R137, R138: 10k; R_1206_3216Metric; MPN AC1206JR-0710KL
R127, R128, R129, R130: 10k; R_0402_1005Metric; MPN AC0402JR-0710KL
R131, R136: 5k1; R_0603_1608Metric; not fitted
R139: 4k7; R_0402_1005Metric; MPN AC0402FR-074K7L
U12: MAX9926; QSOP-16_3.9x4.9mm_P0.635mm; MPN MAX9926UAEE+T

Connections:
/5VA: C87.1, C88.1, D25.2 (A), D26.2 (A), R123.2, R127.1, R130.1, R139.2, U12.14 (VCC); also elsewhere on the board
/CAM+: R132.1; also elsewhere on the board
/CAM-/HALL: R124.1, R125.1; also elsewhere on the board
/CAM_UC: R127.2, R128.2, U12.4 (COUT1); also elsewhere on the board
/CRANK+: R137.1; also elsewhere on the board
/CRANK-: R134.1; also elsewhere on the board
/CRANK_UC: R129.2, R130.2, U12.5 (COUT2); also elsewhere on the board
/VSS: D27.1 (K); also elsewhere on the board
/VSS_UC: D27.2 (A), R139.1; also elsewhere on the board
GND: C87.2, C88.2, U12.1 (INT_THRS1), U12.3 (BIAS1), U12.6 (BIAS2), U12.8 (INT_THRS2), U12.11 (GND), U12.12 (DIRN), U12.13 (ZERO_EN); also elsewhere on the board
unnamed: D25.1 (K), R128.1
unnamed: D26.1 (K), R129.1
unnamed: R123.1, R124.2
unnamed: R125.2, R126.1
unnamed: R132.2, R133.1
unnamed: R134.2, R135.1
unnamed: R137.2, R138.1
unnamed: C89.2, R131.1, R133.2, U12.16 (IN1+)
unnamed: C89.1, R126.2, R131.2, U12.15 (IN1-)
unnamed: C90.1, R136.2, R138.2, U12.9 (IN2+)
unnamed: C90.2, R135.2, R136.1, U12.10 (IN2-)

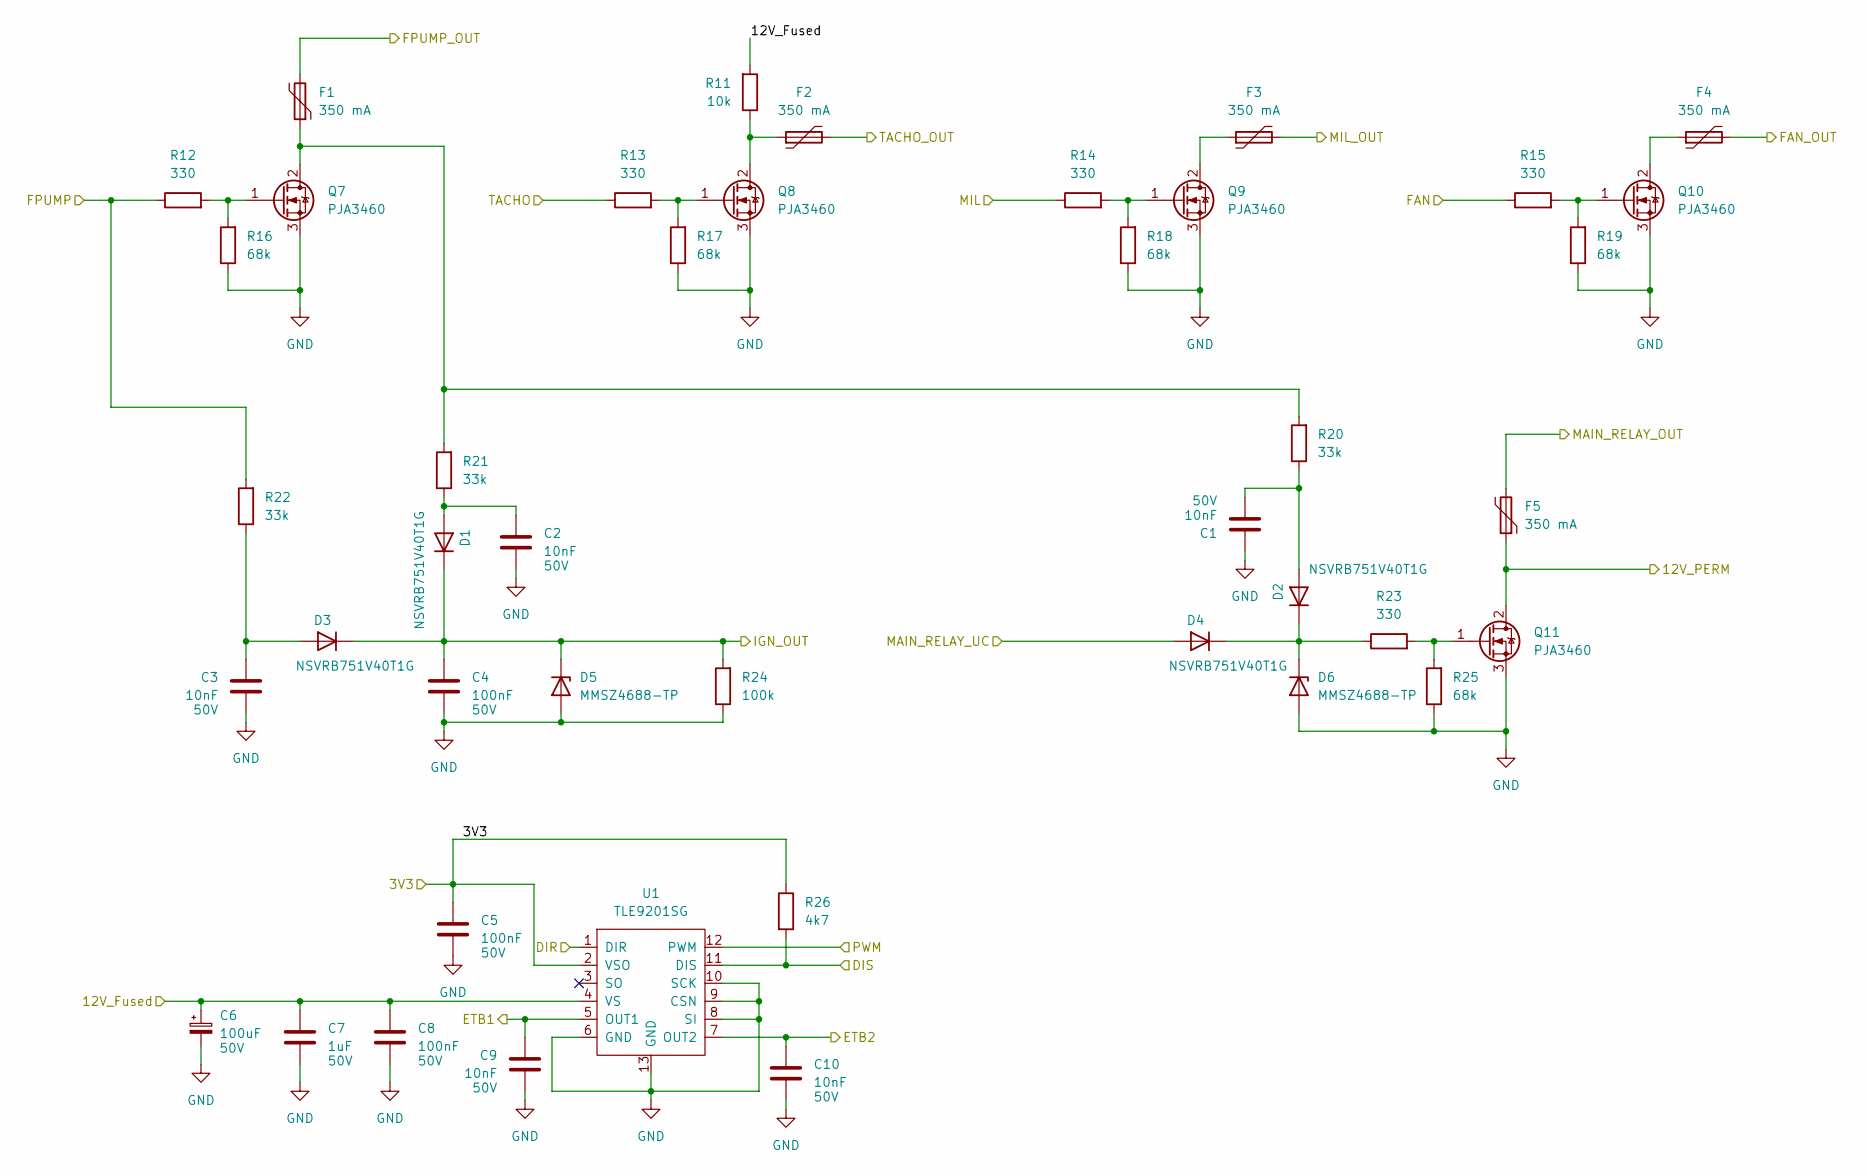
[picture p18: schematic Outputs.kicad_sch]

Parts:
C1, C2, C3, C9, C10: 10nF; C_0402_1005Metric; MPN GCM155R71H103MA55D
C4, C5, C8: 100nF; C_0402_1005Metric; MPN CL05B104KB54PNC
C6: 100uF; CP_Elec_8x10; MPN UCD1H101MNL1GS
C7: 1uF; C_0805_2012Metric; MPN CL21B105KBFNNNG
D1, D2, D3, D4: NSVRB751V40T1G; D_SOD-323; MPN NSVRB751V40T1G
D5, D6: MMSZ4688-TP; D_SOD-123; MPN MMSZ4688-TP
F1, F2, F3, F4, F5: 350 mA; Fuse_1206_3216Metric; MPN 0ZCJ0035FF2G
Q7, Q8, Q9, Q10, Q11: PJA3460; SOT-23-3; MPN PJA3460-AU_R1_000A1
R11: 10k; R_1206_3216Metric; MPN AC1206JR-0710KL
R12, R13, R14, R15, R23: 330; R_0402_1005Metric; MPN AC0402FR-07330RL
R16, R17, R18, R19, R25: 68k; R_0402_1005Metric; MPN AC0402FR-0768KL
R20, R21, R22: 33k; R_0402_1005Metric; MPN AC0402FR-0733KL
R24: 100k; R_0402_1005Metric; MPN AC0402FR-07100KL
R26: 4k7; R_0402_1005Metric; MPN AC0402FR-074K7L
U1: TLE9201SG; Infineon_PG-DSO-12-17_ThermalVias; MPN TLE9201SGAUMA1

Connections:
/3V3: C5.1, R26.1, U1.2 (VSO); also elsewhere on the board
/12V_RAW: C6.1, C7.1, C8.1, R11.2, U1.4 (VS); also elsewhere on the board
/ETB1: C9.1, U1.5 (OUT1); also elsewhere on the board
/ETB2: C10.1, U1.7 (OUT2); also elsewhere on the board
/ETB_DIR: U1.1 (DIR); also elsewhere on the board
/ETB_DIS: R26.2, U1.11 (DIS); also elsewhere on the board
/ETB_PWM: U1.12 (PWM); also elsewhere on the board
/FAN_OUT: F4.2; also elsewhere on the board
/FAN_UC: R15.1; also elsewhere on the board
/FPUMP_RELAY: F1.2; also elsewhere on the board
/FPUMP_UC: R12.1, R22.2; also elsewhere on the board
/MAIN_RELAY: F5.2; also elsewhere on the board
/MAIN_RELAY_UC: D4.2 (A); also elsewhere on the board
/MIL: F3.2; also elsewhere on the board
/MIL_UC: R14.1; also elsewhere on the board
/Outputs/12V_PERM: F5.1, Q11.2 (D); also elsewhere on the board
/TACHO_OUT: F2.2; also elsewhere on the board
/TACHO_UC: R13.1; also elsewhere on the board
/VIGN: C4.1, D1.1 (K), D3.1 (K), D5.1 (K), R24.2; also elsewhere on the board
GND: C1.1, C2.2, C3.2, C4.2, C5.2, C6.2, C7.2, C8.2, C9.2, C10.2, D5.2 (A), D6.2 (A), Q7.3 (S), Q8.3 (S), Q9.3 (S), Q10.3 (S), Q11.3 (S), R16.1, R17.1, R18.1, R19.1, R24.1, R25.1, U1.6 (GND), U1.8 (SI), U1.9 (CSN), U1.10 (SCK), U1.13 (GND); also elsewhere on the board
unnamed: C2.1, D1.2 (A), R21.1
unnamed: C1.2, D2.2 (A), R20.1
unnamed: D2.1 (K), D4.1 (K), D6.1 (K), R23.1
unnamed: C3.1, D3.2 (A), R22.1
unnamed: F1.1, Q7.2 (D), R20.2, R21.2
unnamed: Q7.1 (G), R12.2, R16.2
unnamed: F2.1, Q8.2 (D), R11.1
unnamed: Q8.1 (G), R13.2, R17.2
unnamed: F3.1, Q9.2 (D)
unnamed: Q9.1 (G), R14.2, R18.2
unnamed: F4.1, Q10.2 (D)
unnamed: Q10.1 (G), R15.2, R19.2
unnamed: Q11.1 (G), R23.2, R25.2

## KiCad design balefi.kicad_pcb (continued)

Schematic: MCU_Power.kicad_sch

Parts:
C93, C96, C97, C100, C101, C102, C104: 10uF; C_1206_3216Metric; MPN CL31A106KBHNNNE
C94, C95, C98, C99, C103, C105: 100nF; C_0402_1005Metric; MPN CL05B104KB54PNC
D28: LED; LED_0603_1608Metric; MPN 150060AS75000
D29: V3P6HM3_A/H; Vishay_SMPA; MPN V3P6HM3_A/H
F6, F7: 350 mA; Fuse_1206_3216Metric; MPN 0ZCJ0035FF2G
FB1: 600 ohm 500mA; R_0603_1608Metric; MPN BLM18AG601SN1D
Q12, Q14: DMG2307LQ-7; SOT-23-3; MPN DMG2307LQ-7
Q13, Q15: RUC002N05HZGT116; SOT-23; MPN RUC002N05HZGT116
R142, R143, R144, R145, R146: 10k; R_0402_1005Metric; MPN AC0402JR-0710KL
U13: REF3033; SOT-23; MPN REF3033AIDBZR
U14: NCV1117DT33T5G; TO-252-2; MPN NCV1117DT33T5G

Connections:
/3V3: C104.1, F7.2; also elsewhere on the board
/5V: C93.1, C94.2, C97.1, C98.2, D29.1 (K), Q12.3 (S), R143.2, U13.1 (IN), U14.3 (VI); also elsewhere on the board
/5VA: C102.1, F6.2; also elsewhere on the board
/MCU_module/3V3: C99.2, C100.1, D28.2 (A), FB1.1, Q14.3 (S), R145.2, U14.2 (VO); also elsewhere on the board
/MCU_module/V33A: C101.1, FB1.2; also elsewhere on the board
/MCU_module/V33REF: C95.2, C96.1, U13.2 (OUT); also elsewhere on the board
/MCU_module/VBUS: D29.2 (A); also elsewhere on the board
/PWR_EN: Q13.1 (G), Q15.1 (G), R144.2, R146.2; also elsewhere on the board
GND: C93.2, C94.1, C95.1, C96.2, C97.2, C98.1, C99.1, C100.2, C101.2, C102.2, C103.1, C104.2, C105.1, Q13.3 (S), Q15.3 (S), R142.2, R144.1, R146.1, U13.3 (GND), U14.1 (GND); also elsewhere on the board
unnamed: D28.1 (K), R142.1
unnamed: C103.2, F6.1, Q12.2 (D)
unnamed: Q12.1 (G), Q13.2 (D), R143.1
unnamed: C105.2, F7.1, Q14.2 (D)
unnamed: Q14.1 (G), Q15.2 (D), R145.1

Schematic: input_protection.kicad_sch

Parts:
C72, C73, C74, C75: 10nF; C_0402_1005Metric; MPN GCM155R71H103MA55D
D23: NUP4202W1T2G; SOT-363_SC-70-6; MPN NUP4202W1T2G
R92, R93, R94, R95, R100, R101, R102, R103: 680k; R_0402_1005Metric; MPN WR06X6803FTL
R96, R97, R98, R99: 4k7; R_0402_1005Metric; MPN AC0402FR-074K7L

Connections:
/5VA: D23.5, R92.2, R93.2, R94.2, R95.2; also elsewhere on the board
/MCU_module/input_protection_1/OUT1: C72.1, D23.6, R96.2; also elsewhere on the board
/MCU_module/input_protection_1/OUT2: C73.1, D23.4, R97.2; also elsewhere on the board
/MCU_module/input_protection_1/OUT3: C74.1, D23.1, R98.2; also elsewhere on the board
/MCU_module/input_protection_1/OUT4: C75.1, D23.3, R99.2; also elsewhere on the board
/PPS1_IN: R94.1, R98.1, R102.2; also elsewhere on the board
/PPS2_IN: R95.1, R99.1, R103.2; also elsewhere on the board
/TPS1: R92.1, R96.1, R100.2; also elsewhere on the board
/TPS2: R93.1, R97.1, R101.2; also elsewhere on the board
GND: C72.2, C73.2, C74.2, C75.2, D23.2, R100.1, R101.1, R102.1, R103.1; also elsewhere on the board

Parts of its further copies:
C68, C69, C70, C71, C76, C77, C78, C79: 10nF; C_0402_1005Metric; MPN GCM155R71H103MA55D
D22, D24: NUP4202W1T2G; SOT-363_SC-70-6; MPN NUP4202W1T2G
R80, R81, R82, R83, R88, R89, R90, R91, R104, R105, R106, R107, R112, R113, R114, R115: 680k; R_0402_1005Metric; MPN WR06X6803FTL
R84, R85, R86, R87, R108, R109, R110, R111: 4k7; R_0402_1005Metric; MPN AC0402FR-074K7L

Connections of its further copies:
/5VA: D22.5, D24.5, R80.2, R81.2, R82.2, R83.2, R104.2, R105.2, R106.2, R107.2; also elsewhere on the board
/CAM_UC: R105.1, R109.1, R113.2; also elsewhere on the board
/CLT: R81.1, R85.1, R89.2; also elsewhere on the board
/CRANK_UC: R104.1, R108.1, R112.2; also elsewhere on the board
/IAT: R80.1, R84.1, R88.2; also elsewhere on the board
/KNOCK_UC: R107.1, R111.1, R115.2; also elsewhere on the board
/MAP: R82.1, R86.1, R90.2; also elsewhere on the board
/MCU_module/input_protection_2/OUT1: C68.1, D22.6, R84.2; also elsewhere on the board
/MCU_module/input_protection_2/OUT2: C69.1, D22.4, R85.2; also elsewhere on the board
/MCU_module/input_protection_2/OUT3: C70.1, D22.1, R86.2; also elsewhere on the board
/MCU_module/input_protection_2/OUT4: C71.1, D22.3, R87.2; also elsewhere on the board
/MCU_module/input_protection_3/OUT1: C76.1, D24.6, R108.2; also elsewhere on the board
/MCU_module/input_protection_3/OUT2: C77.1, D24.4, R109.2; also elsewhere on the board
/MCU_module/input_protection_3/OUT3: C78.1, D24.1, R110.2; also elsewhere on the board
/MCU_module/input_protection_3/OUT4: C79.1, D24.3, R111.2; also elsewhere on the board
/VMAIN_UC: R83.1, R87.1, R91.2; also elsewhere on the board
/VSS_UC: R106.1, R110.1, R114.2; also elsewhere on the board
GND: C68.2, C69.2, C70.2, C71.2, C76.2, C77.2, C78.2, C79.2, D22.2, D24.2, R88.1, R89.1, R90.1, R91.1, R112.1, R113.1, R114.1, R115.1; also elsewhere on the board

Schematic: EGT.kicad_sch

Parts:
C107: 1uF; C_0805_2012Metric; MPN CL21B105KBFNNNG
C108: 100nF; C_0402_1005Metric; MPN CL05B104KB54PNC
C109: 10nF; C_0402_1005Metric; MPN GCM155R71H103MA55D
D31: SZNUP2105L; SOT-23; MPN SZNUP2105LT1G
L3, L4: BLM18SP102SN1D; L_0603_1608Metric_Pad1.05x0.95mm_HandSolder
R153: 22; R_0402_1005Metric; MPN AC0402FR-0722RL
U16: MAX31855KASA; SOIC-8_3.9x4.9mm_P1.27mm

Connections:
/EGT+: D31.2 (K), L3.2; also elsewhere on the board
/EGT-: D31.1 (K), L4.2; also elsewhere on the board
/MCU_module/SPI3_CS: U16.6 (~CS); also elsewhere on the board
/MCU_module/SPI3_MISO: R153.1; also elsewhere on the board
/MCU_module/SPI3_SCK: U16.5 (SCK); also elsewhere on the board
/MCU_module/V33A: C107.1, C108.2, U16.4 (V_CC); also elsewhere on the board
GND: C107.2, C108.1, D31.3 (A), U16.1 (GND); also elsewhere on the board
unnamed: R153.2, U16.7 (SO)
unnamed: C109.2, L3.1, U16.3 (T+)
unnamed: C109.1, L4.1, U16.2 (T-)

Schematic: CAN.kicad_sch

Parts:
C65, C67: 100nF; C_0402_1005Metric; MPN CL05B104KB54PNC
C66: 4.7nF; C_0402_1005Metric; MPN GCM155R71H472KA37J
D21: SZNUP2105L; SOT-23; MPN SZNUP2105LT1G
R76, R79: 10; R_0402_1005Metric; MPN AC0402FR-0710RL
R77, R78: 60.4; R_0805_2012Metric; MPN AC0805FR-0760R4L
U10: TJA1051T/3/2Z; SOIC-8_3.9x4.9mm_P1.27mm; MPN TJA1051T/3/2Z

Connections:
/5V: C65.1, U10.3 (VCC); also elsewhere on the board
/CANH: D21.1 (K), R76.2, R77.1; also elsewhere on the board
/CANL: D21.2 (K), R78.2, R79.2; also elsewhere on the board
/MCU_module/3V3: C67.1, U10.5 (VIO); also elsewhere on the board
/MCU_module/CAN_RX: U10.4 (RXD); also elsewhere on the board
/MCU_module/CAN_TX: U10.1 (TXD); also elsewhere on the board
GND: C65.2, C66.2, C67.2, D21.3 (A), U10.2 (GND), U10.8 (S); also elsewhere on the board
unnamed: C66.1, R77.2, R78.1
unnamed: R76.1, U10.7 (CANH)
unnamed: R79.1, U10.6 (CANL)

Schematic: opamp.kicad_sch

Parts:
C60: 100nF; C_0402_1005Metric; MPN CL05B104KB54PNC
C61, C62, C63, C64: 390pF; C_0402_1005Metric; MPN GCM155R71H391KA37D
R68, R69, R70, R71, R72, R73, R74, R75: 2k7; R_0402_1005Metric; MPN AC0402FR-072K7L
U9: TLV9064; TSSOP-14_4.4x5mm_P0.65mm; MPN TLV9064QPWRQ1

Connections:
/5VA: C60.1, U9.4 (V+); also elsewhere on the board
/MCU_module/input_protection_1/OUT1: U9.3 (+); also elsewhere on the board
/MCU_module/input_protection_1/OUT2: U9.5 (+); also elsewhere on the board
/MCU_module/input_protection_1/OUT3: U9.10 (+); also elsewhere on the board
/MCU_module/input_protection_1/OUT4: U9.12 (+); also elsewhere on the board
/PPS1_IN: C63.1, R72.2, R73.2; also elsewhere on the board
/PPS2_IN: C64.1, R74.2, R75.2; also elsewhere on the board
/TPS1: C61.1, R68.2, R69.2; also elsewhere on the board
/TPS2: C62.1, R70.2, R71.2; also elsewhere on the board
GND: C60.2, C61.2, C62.2, C63.2, C64.2, R69.1, R71.1, R73.1, R75.1, U9.11 (V-); also elsewhere on the board
unnamed: R68.1, U9.1, U9.2 (-)
unnamed: R70.1, U9.6 (-), U9.7
unnamed: R72.1, U9.8, U9.9 (-)
unnamed: R74.1, U9.13 (-), U9.14

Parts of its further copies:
C32, C37: 100nF; C_0402_1005Metric; MPN CL05B104KB54PNC
C33, C34, C35, C36, C38, C39, C40, C41: 390pF; C_0402_1005Metric; MPN GCM155R71H391KA37D
R36, R37, R38, R39, R40, R41, R42, R43, R44, R45, R46, R47, R48, R49, R50, R51: 2k7; R_0402_1005Metric; MPN AC0402FR-072K7L
U5, U6: TLV9064; TSSOP-14_4.4x5mm_P0.65mm; MPN TLV9064QPWRQ1

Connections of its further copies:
/5VA: C32.1, C37.1, U5.4 (V+), U6.4 (V+); also elsewhere on the board
/CAM_UC: C39.1, R46.2, R47.2; also elsewhere on the board
/CLT: C34.1, R38.2, R39.2; also elsewhere on the board
/CRANK_UC: C38.1, R44.2, R45.2; also elsewhere on the board
/IAT: C33.1, R36.2, R37.2; also elsewhere on the board
/MAP: C35.1, R40.2, R41.2; also elsewhere on the board
/MCU_module/KNOCK: C41.1, R50.2, R51.2; also elsewhere on the board
/MCU_module/input_protection_2/OUT1: U5.3 (+); also elsewhere on the board
/MCU_module/input_protection_2/OUT2: U5.5 (+); also elsewhere on the board
/MCU_module/input_protection_2/OUT3: U5.10 (+); also elsewhere on the board
/MCU_module/input_protection_2/OUT4: U5.12 (+); also elsewhere on the board
/MCU_module/input_protection_3/OUT1: U6.3 (+); also elsewhere on the board
/MCU_module/input_protection_3/OUT2: U6.5 (+); also elsewhere on the board
/MCU_module/input_protection_3/OUT3: U6.10 (+); also elsewhere on the board
/MCU_module/input_protection_3/OUT4: U6.12 (+); also elsewhere on the board
/VMAIN_UC: C36.1, R42.2, R43.2; also elsewhere on the board
/VSS_UC: C40.1, R48.2, R49.2; also elsewhere on the board
GND: C32.2, C33.2, C34.2, C35.2, C36.2, C37.2, C38.2, C39.2, C40.2, C41.2, R37.1, R39.1, R41.1, R43.1, R45.1, R47.1, R49.1, R51.1, U5.11 (V-), U6.11 (V-); also elsewhere on the board
unnamed: R36.1, U5.1, U5.2 (-)
unnamed: R38.1, U5.6 (-), U5.7
unnamed: R40.1, U5.8, U5.9 (-)
unnamed: R42.1, U5.13 (-), U5.14
unnamed: R44.1, U6.1, U6.2 (-)
unnamed: R46.1, U6.6 (-), U6.7
unnamed: R48.1, U6.8, U6.9 (-)
unnamed: R50.1, U6.13 (-), U6.14

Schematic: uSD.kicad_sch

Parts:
C91: 10uF; C_1206_3216Metric; MPN CL31A106KBHNNNE
C92: 100nF; C_0402_1005Metric; MPN CL05B104KB54PNC
J4: MEM2067-02-180-00-A; MPN MEM2067-02-180-00-A
R140: 10k; R_0402_1005Metric; MPN AC0402JR-0710KL
R141: 1R; R_0603_1608Metric; MPN AF0603FR-071RL
R152: 22; R_0402_1005Metric; MPN AC0402FR-0722RL

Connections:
/MCU_module/3V3: R141.1; also elsewhere on the board
/MCU_module/SPI1_CS1: J4.2 (CD/DAT3), R140.1; also elsewhere on the board
/MCU_module/SPI1_MISO: J4.7 (DAT0), R152.1, R152.2; also elsewhere on the board
/MCU_module/SPI1_MOSI: J4.3 (CMD); also elsewhere on the board
/MCU_module/SPI1_SCK: J4.5 (CLK); also elsewhere on the board
GND: C91.2, C92.2, J4.6 (VSS), J4.TAB_1, J4.TAB_2, J4.TAB_3, J4.TAB_4; also elsewhere on the board
unnamed: C91.1, C92.1, J4.4 (VDD), R140.2, R141.2

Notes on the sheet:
MEM2067-02-180-00-A

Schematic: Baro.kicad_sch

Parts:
C106: 100nF; C_0402_1005Metric; MPN CL05B104KB54PNC
U15: LPS25HB; ST_HLGA-10_2.5x2.5mm_P0.6mm_LayoutBorder3x2y

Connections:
/MCU_module/3V3: C106.1, U15.1 (Vdd_IO), U15.6 (~CS), U15.10 (VDD); also elsewhere on the board
/MCU_module/I2C_SCL: U15.2 (SCL); also elsewhere on the board
/MCU_module/I2C_SDA: U15.4 (SDA); also elsewhere on the board
GND: C106.2, U15.3 (GND), U15.5 (SA0), U15.8 (GND), U15.9 (GND); also elsewhere on the board

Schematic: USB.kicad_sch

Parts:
D30: PRTR5V0U2X; SOT-143; MPN PRTR5V0U2AX,215
J5: Conn_01x06_Pin; JST_PH_B6B-PH-K_1x06_P2.00mm_Vertical; MPN B6B-PH-K-S
R147, R148: 5k1; R_0603_1608Metric

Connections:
/MCU_module/D+: D30.3 (I/O2), J5.2; also elsewhere on the board
/MCU_module/D-: D30.2 (I/O1), J5.3; also elsewhere on the board
/MCU_module/USB/CC1: J5.5, R147.1
/MCU_module/USB/CC2: J5.4, R148.1
/MCU_module/VBUS: D30.4 (VCC), J5.6; also elsewhere on the board
GND: D30.1 (GND), J5.1, R147.2, R148.2; also elsewhere on the board

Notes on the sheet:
Add USB ESD protection and CMC

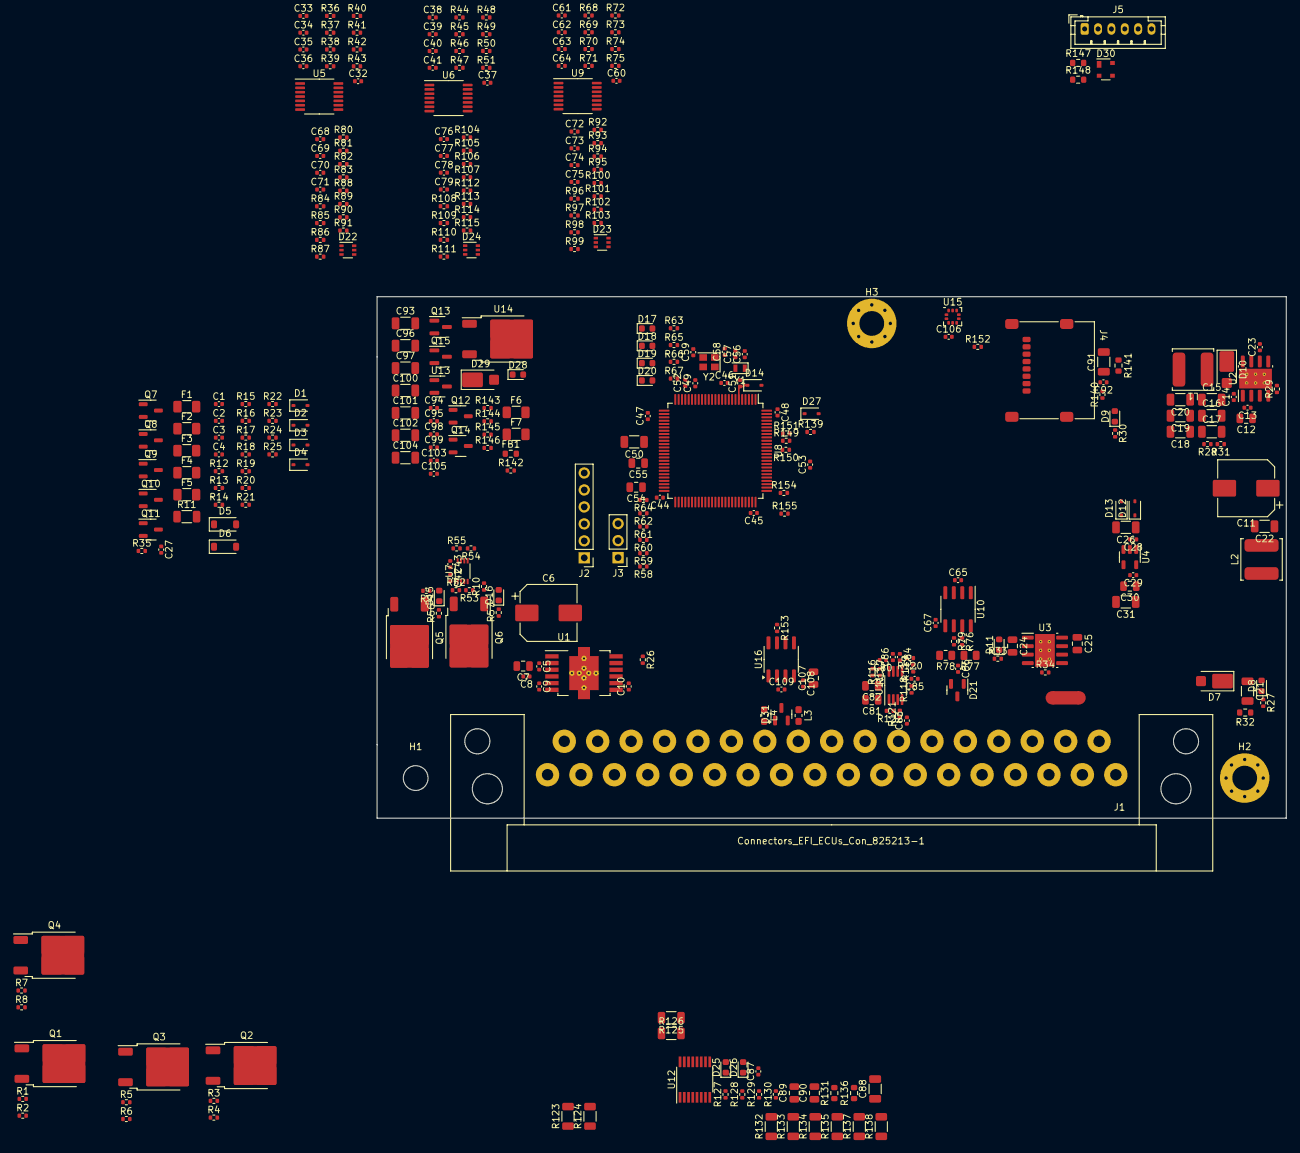
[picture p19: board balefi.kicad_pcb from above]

Board: 4 copper layers, 136.0 x 78.0 mm, 349 parts (0 on the bottom side), 204 nets.

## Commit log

2024-02-28 Added submodule kicad-libraries
2024-02-28 First PCB design commit
    [hellen-balefi.kicad_pcb, hellen-balefi.kicad_sch]
2024-02-28 Change file names
    [balefi.kicad_pcb, balefi.kicad_sch]
2024-02-28 Added outer dimmensions for PCB, added origin point
    [balefi.kicad_pcb]
2024-02-28 [skip actions] Auto-generated board v2.1
    [balefi-B_Cu.gbl, balefi-B_Mask.gbs, balefi-B_Paste.gbp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]
2024-03-05 Started designing schematic
    [ETB.kicad_sch, Ignition.kicad_sch, Injection.kicad_sch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]
2024-06-03 a lot of changes
    [Baro.kicad_sch, CAN.kicad_sch, EGT.kicad_sch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]

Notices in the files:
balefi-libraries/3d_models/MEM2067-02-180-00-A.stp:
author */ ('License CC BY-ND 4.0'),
